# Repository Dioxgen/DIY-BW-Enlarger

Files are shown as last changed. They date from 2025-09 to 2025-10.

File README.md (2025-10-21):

# 基于 RGB 光源的黑白放大机设计笔记

###### 【Designed By Dioxgen】  

## 概述：

如题，这是一篇关于 DIY 黑白放大机的笔记。该放大机的核心材料为**黑胡桃木 + 金属**，DIY 特点在于通过 RGB 光源替代传统的方案、引入精准对焦系统、设计兼容多画幅底片磁吸片夹等，实现低成本、高自由度的黑白暗房创作。

本项目尽量兼顾**功能与成本**的平衡，确保可行性以便于复刻。按照惯例，全部资料开源处理。

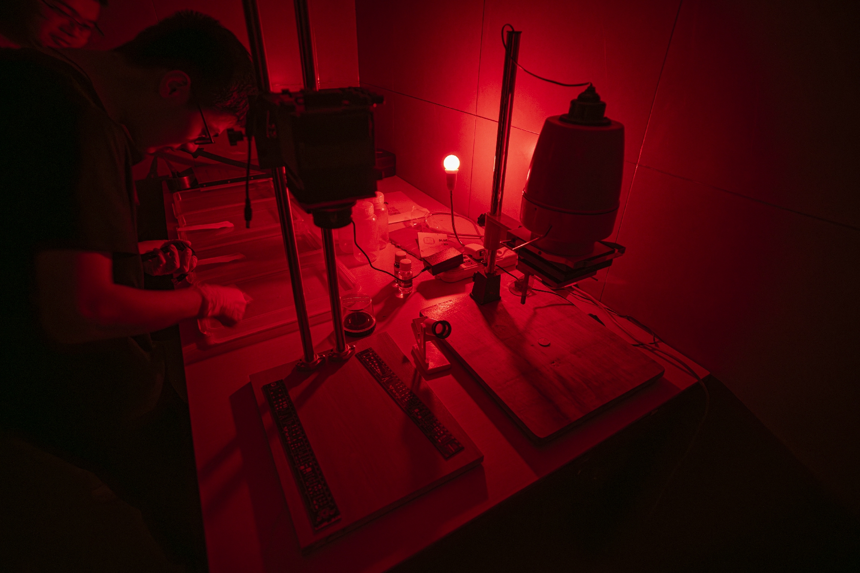
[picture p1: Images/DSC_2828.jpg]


### FAQ：

成本如何？

> < 400￥

耗时？

> 3 天收集材料，3 天组装，一周可完成。

支持的底片？

> 135 底片与 66 画幅底片。为黑白负片设计，彩色负片**可能**不适用。

放大倍率？

> 可以自由组合底板大小与主杆的高度，设计为至少放大 8 倍。（最大倍率也取决于放大镜头）

操控方面？

> 滑块移动主体，滑台移动对焦组，整机精度可用。

如何复刻？

> 接着看下去。

### 版本组合：

| 总版本 | 片夹 | PCB  |
| --- | ---- | ---- |
| 1.0 | 1.0  | 1.0  |
| 2.0 | 2.0  | 2.0  |

| 具体项目 | 版本 | 说明 |
| --- | --- | --- |
| 片夹 | 1.0 | 多玻璃易产生牛顿环 |
| | 2.0（待完成） | 单玻璃 |
| PCB | 1.0 | 电位器正负极混乱，单联电位器不稳定 |
| | 2.0 | 解决V1.0问题，优化布局 |

> *（截至 2025.08）*

## 结构设计：

该放大机的基本结构由我参考了杜斯特（Durst）的各类放大机的共性设计，并结合本人 DIY 与嵌入式开发经验做出改动迭代得到。

主材料选择了胡桃木，其油分不足，需要做木蜡保护。

### 主杆：

主杆由两长度 **1m**，**Φ=20mm** 的钢轴，搭配 **SCS20UU** 带锁紧的滑块制成。将轴切割后插入底座打好的孔洞中，再用法兰座进一步固定即可。

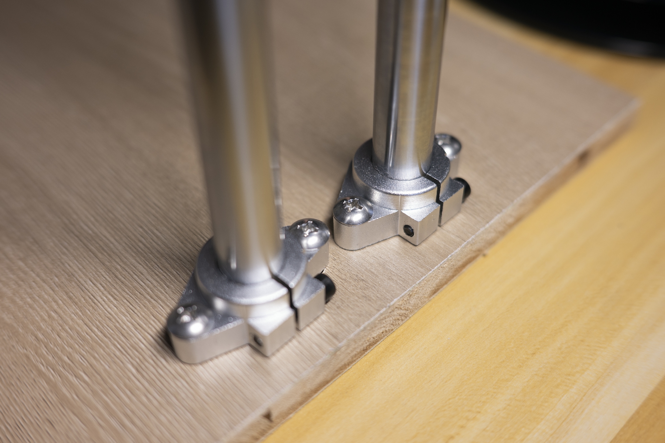
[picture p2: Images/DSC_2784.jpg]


这两根钢轴若是实心的，则奇重无比。取碳钢密度为 *7850kg/m³*，则总质量（2x1m）约为 *4.9kg*，实际镀铬硬轴会更重。若选用外径 *20mm*，内径 *15mm* 钢管，这一数值可缩减至 *2.15kg*。但注意钢管的**公差**会大很多，可能导致连法兰座都无法安装，且**直线度**远低于镀铬硬轴，另外异味较重。

将滑块插入钢轴，随后，使用木板连接两滑块，放大机主体可与其通过角码进一步连接。

------

### 底座：

从强度、形变、成本等方面综合考虑，我最终选择了一整块 30×37.5×2cm 的**胶合木板**作为底板，预留两处孔洞装配主杆，底部装配四处防滑垫。

> 详细的论述可以参考`\Datasheet\其他\底板推导.md`

------

### 光源：

光源的选择与所要处理的感光材料息息相关。本项目制作的是黑白放大机，选择的光源优先适配**黑白相纸**。

从材质上看，黑白相纸分为 FB 纸基相纸（Fiber-based）和 RC 涂塑相纸。涂塑相纸表面涂布 PE（Polyethylene，聚乙烯）。

可变反差黑白相纸的乳剂可以理解为由两层构成：

> 1. 高反差层：感蓝光。
> 2. 低反差层：感绿光。
>

相纸最终反差取决于两层乳剂的**曝光比例**，而可变反差滤镜（Variable Contrast Filters，即 VC 滤镜）作为黑白暗房放大中的关键工具，其核心原理就是通过**色光选择性调控**，利用黑白相纸乳剂对不同色光的敏感性差异，通过控制蓝光与绿光的入射强度比例实现调节相纸反差的效果。

> 操作举例：使用 Y（黄色）滤镜过滤蓝光实现低反差； M（品红）滤镜过滤绿光实现高反差。

我最终选择了**凯瑞的可变反差黑白涂塑相纸（KENTMERE VC SELECT RC）**，~~因为便宜~~，那么基于其特性进一步考虑光源的选择：

#### 1）卤素灯：

传统的放大机光源大多为**卤素灯**，光谱连续且覆盖完整（显色指数 CRI > 95），能充分激发相纸乳剂。然而灯泡寿命较短（约 50 小时）且功耗较大，长时间曝光还易引发烤片等问题。

#### 2）普通白光 LED：

普通 LED 红外辐射少、能耗低、寿命极长。然而观察光谱可知蓝光峰突出且 480nm 附近波段严重不足，CRI 通常 ≤ 80，缺乏连续光谱，不适合相纸曝光。

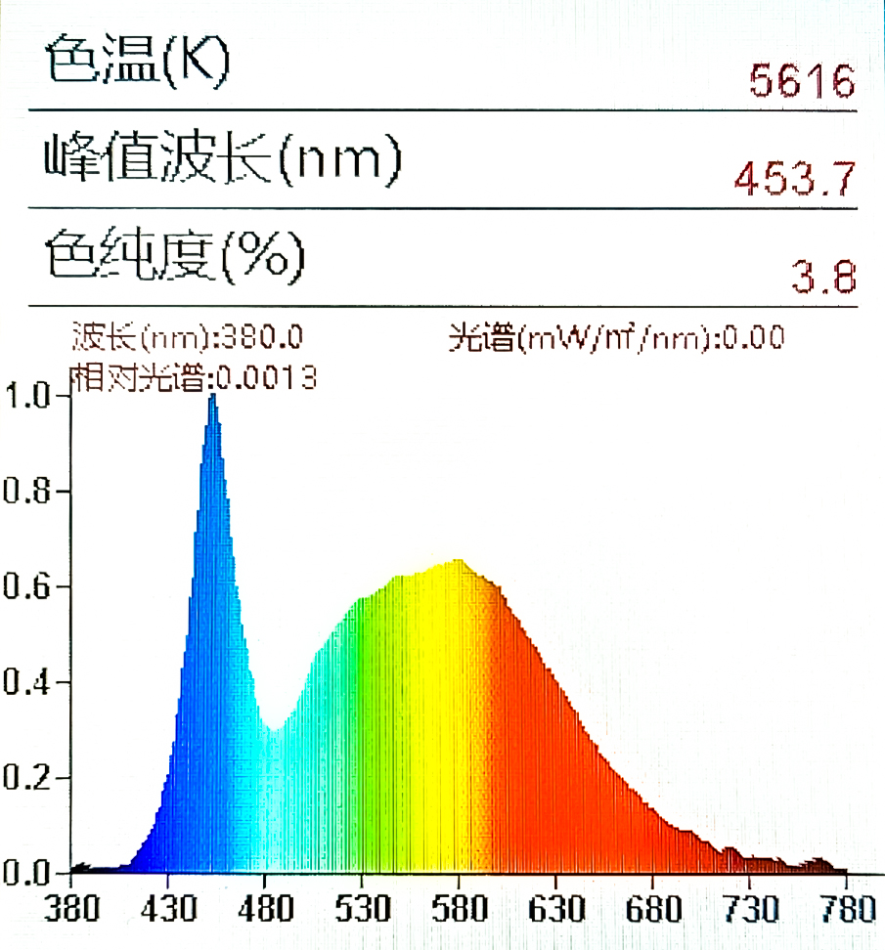
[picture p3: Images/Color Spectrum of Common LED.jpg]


<center>普通 LED 实测光谱拍屏</center>

##### # 特殊的高 CRI LED：

可以使用单个 **COB 光源**，通过菲涅尔透镜获得平行光，也是一种适宜的解决方案。

#### 3）RGB 灯珠：

通过独立控制红（R）、绿（G）、蓝（B）三通道亮度，直接调控相纸双层乳剂的激活比例，无需物理滤镜。

##### # 核心原理：

- 绿光（G） → 激活低反差层 → 降低反差
- 蓝光（B） → 激活高反差层 → 提高反差
- 红光（R） → 黑白相纸几乎不感光，可用于安全灯模式。

| RGB灯珠 | 每通道独立控制输出 |
| :---: | :---: |
| **混光系统** | **扩散板确保光场均匀** |
| **驱动电路** | **PWM 控制色光比例** |
| **控制界面** | **实体按键与旋钮（详见“电控系统”）** |

最常见的 RGB 灯珠莫过于 **5050RGB** 灯珠，该灯珠的数据手册我已归档于 “Datasheet” 文件夹中。其中最重要的参数是光谱：

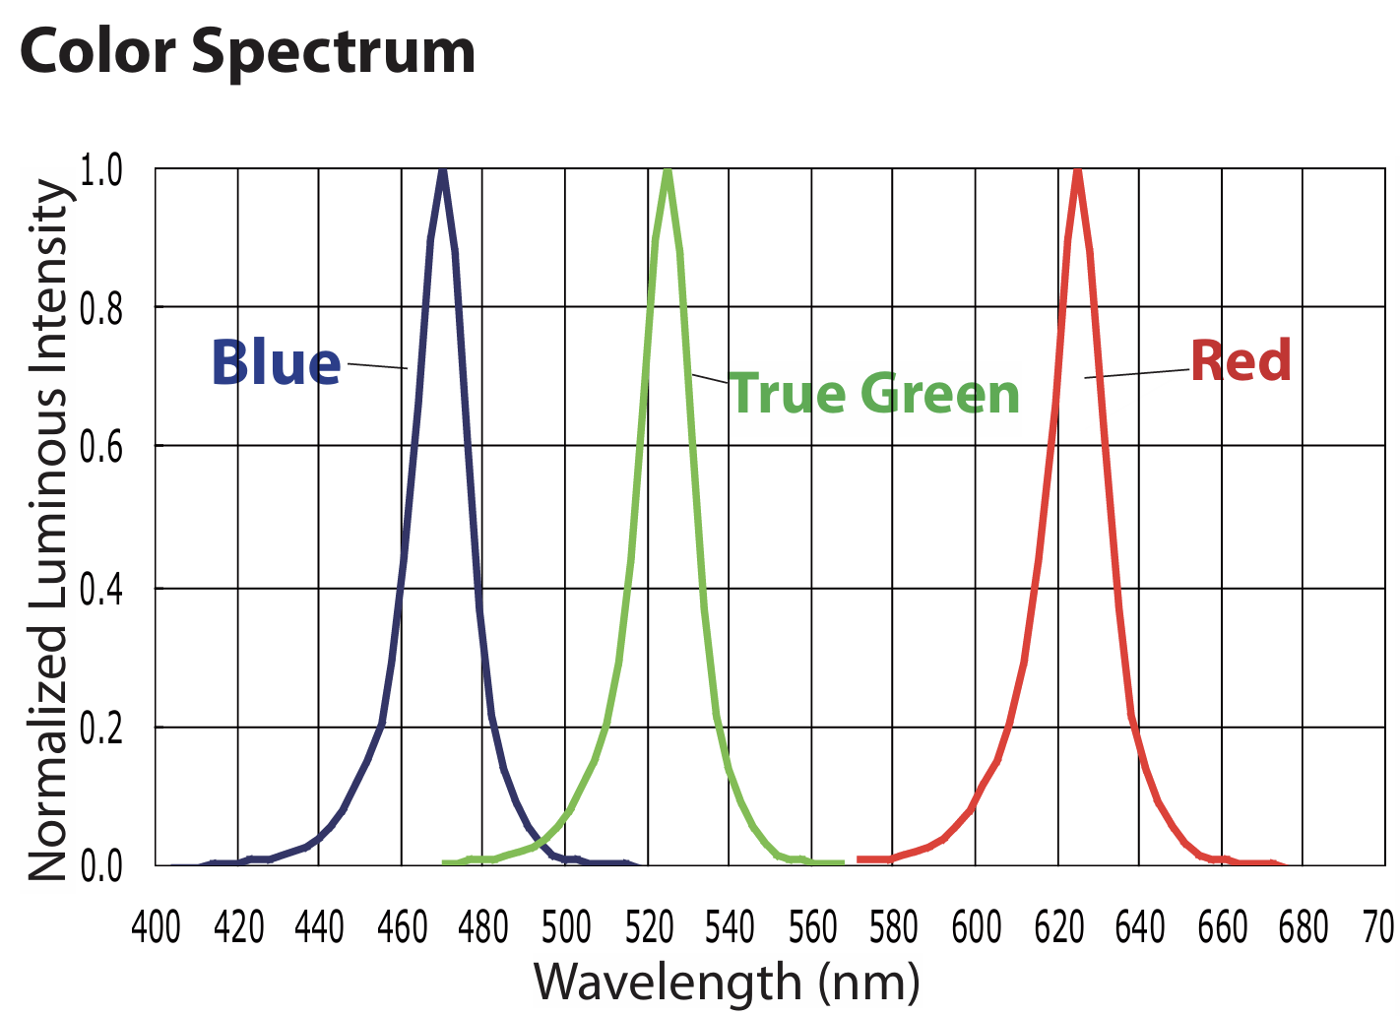
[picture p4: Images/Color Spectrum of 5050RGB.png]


| 颜色 | 最小值（nm） | 典型值（nm） | 最大值（nm） |
| ---- | --- | --- | --- |
| R | 620 | 625 | 630 |
| G | 520 | 525 | 530 |
| B | 460 | 465 | 470 |

单个灯珠最大功耗约 0.3W，使用 8×8 灯板则总功率在 **19W** 左右，比较合适。既然使用灯板，那么通过均光板混光即可。

#### 相纸：

关于 **KENTMERE VC SELECT RC** 的手册中未提及有关波长响应曲线的资料，只在 “Exposure” 中提到：

> VC SELECT is designed for use with **tungsten or tungsten halogen light sources**.
>
> Cold light source enlargers can be used, but they may **limit the contrast range achievable**. 

大意是该相纸被设计用于**钨丝灯或卤素灯光源**，使用冷光源可能导致**低反差**。

但是，我在[KENTMERE PHOTOGRAPHIC : VC SELECT TECHNICAL DATA](https://www.digitaltruth.com/products/kentmere_tech/Kentmere_VC_Select.pdf)中发现了该资料：

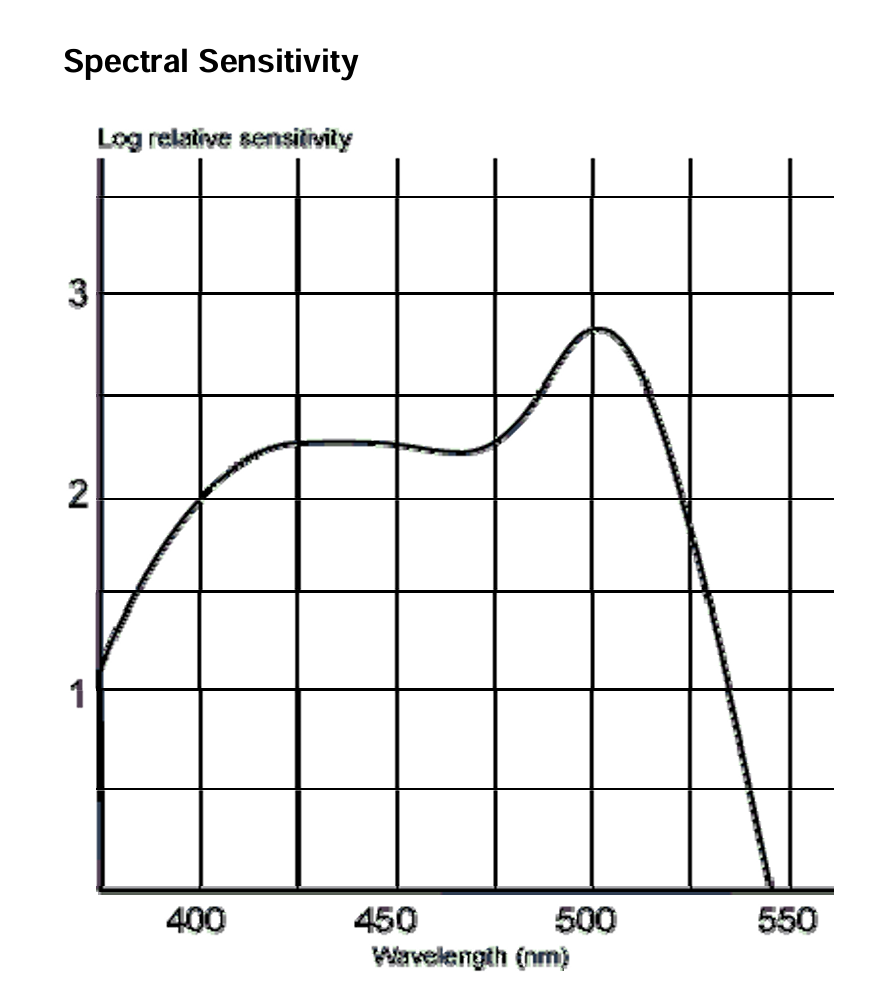
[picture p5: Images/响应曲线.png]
响应曲线


由此可见，比对刚才 RGB 光源的光谱，可以发现相纸对 RGB 的**绿光少敏感**，蓝光完全**在响应范围**内。光源的 G 通道是 520-530nm，B 通道是 460-470nm。由于相纸的响应范围到 525nm，而 G 光源的典型值是 525nm，刚好在边缘，所以 G 光源应该能激活相纸的低反差层。B 光源的 460~470nm 在相纸的响应范围内，应该能激活高反差层。

在标准 VC 相纸中，蓝光用于高反差，绿光用于低反差。但这里相纸的响应范围只到 525nm，且尖峰在 500nm，所以对于 G 光源的 525nm，响应可能稍弱。

基于光谱响应，我们可以估计 G 和 B 通道的曝光时间比例与反差号数的关系。但需要注意的是，由于相纸灵敏度和光源光强可能存在差异，以下估计为**理论值**：

| 反差号数 | B/G 比例范围 | 典型 G-B 组合 | 组合说明 |
| :--- | :--- | :--- | :--- |
| 0 | 0 | (9,0) | 只有绿光，激活低反差层，反差最低 |
| 1 | 0.2 ~ 0.3 | (4,1) | 绿光主导，蓝光微弱，反差略高 |
| 2 | 0.5 ~ 1.0 | (3,2) | 绿光与蓝光平衡偏绿，反差中等 |
| 3 | 1.5 ~ 2.2 | (2,3) | 蓝光与绿光平衡偏蓝，反差中高 |
| 4 | 4.0 ~ 7.0 | (1,4) | 蓝光主导，绿光微弱，反差很高 |
| 5 | ∞ | (0,9) | 只有蓝光，激活高反差层，反差最高 |

后来实际测试，发现 B 通道在 3~6 处相纸反差变化巨大，G 通道总设置为 9 为宜，该现象与上文预测基本吻合。

如果你认为效果欠佳，则再改装为高 CRI 的 COB 光源为宜。

------

### 对焦组：

设计对焦组时需明确对焦行程，该数据可由暗房放大的需求来计算得到。

例1. 假设使用焦段为 **50mm** 的放大镜头将标准的**全画幅**底片放大 **4~8** 倍（对应大约 4x5 至 8x10），则：

1）放大倍率（m）为：
$$
m=\frac{v}{u}
$$
2）透镜公式：
$$
\frac{1}{f}=\frac{1}{u}+\frac{1}{v}
$$
3）结合两公式，可推导出：

1. 物距（1式）：

$$
u=f\cdot\frac{m+1}{m}
$$

2. 像距：

$$
v=f\cdot(m+1)
$$

> 其中：
>
> - f 为镜头焦距（mm）
> - m 为放大倍率
> - u 和 v 的单位为毫米（mm）

4）代入 f 与 m ，得：
$$
m=4时，u=62.5mm，v=250mm
$$

$$
m=8时，u=56.25mm，v=450mm
$$

例2. 假设使用焦段为 **75mm** 的放大镜头将 **66 画幅**中画幅底片放大 **2~4** 倍，同理可得：
$$
m=2时，u=112.5mm，v=225mm
$$

$$
m=4时，u=93.75mm，v=375mm
$$

根据以上数据以及他人反映，应加入冗余设计，考虑到钢轴可能难以加工，则直接使用 **1m** 的即可。对焦组使用行程在 **60~70mm** 的滑台为宜。

##### # 注意：

> 在以上推导中，物距 u 是物体（底片）到镜头的距离；像距 v 是镜头到像（相纸）的距离，不要弄反。
>
> 放大镜头的法兰距（FFD）在此处一般不会对机械设计造成影响。但在某些极端情况下，当期望实现高放大倍率所需的 u 小于 FFD 时，因为对焦操作成像后实际能达到的最小 u 总是 ≥ FFD，所以此时实际的 u ≥ 期望的 u。而根据（1式），在 f 不变的前提下，实际放大倍率 m 将会减小。即镜头无法被调整到足够靠近底片的位置，从而无法达到所需的较高放大倍率，且机械结构可能已达到其调节极限。
>
> 本项目基础卡口为 EF 卡口（FFD ≈ 44mm），可转接放大镜头中更常规的 M39 卡口（FFD = 45.3mm，螺距 1/26 英寸，约 0.977mm）使用。

#### 主要部件：

##### 滑台：

我选择了 **LWZ40-90L** 燕尾槽滑台作为对焦组的核心部件，该组件行程约 70mm，带锁紧，其精密度满足对焦需要。

> 注意是 Z 轴滑台而非 X 轴滑台，Z 轴滑台特有的部件方便了机械设计。

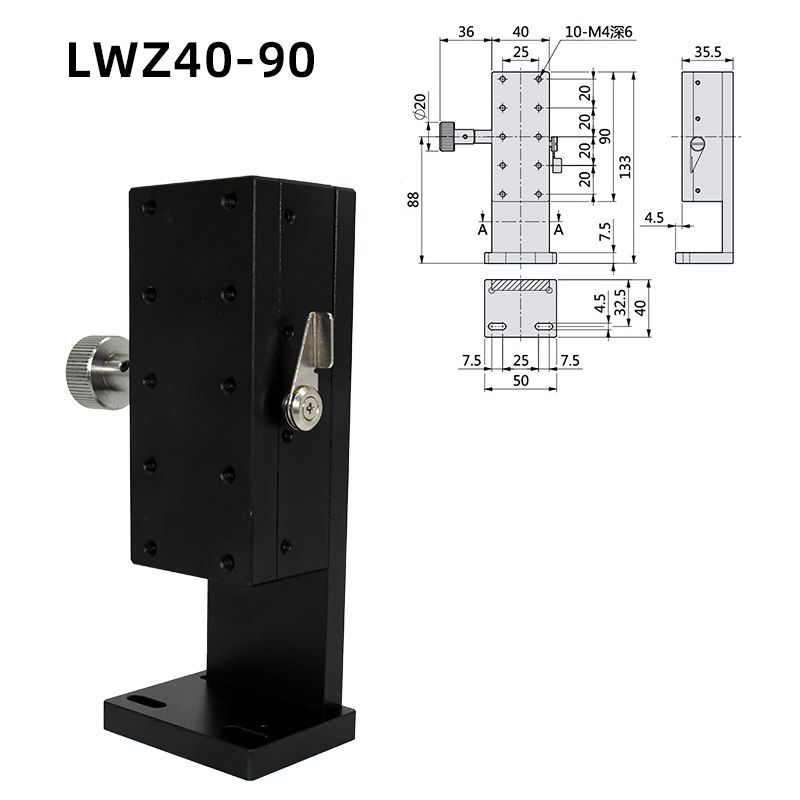
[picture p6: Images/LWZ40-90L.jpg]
LWZ40-90L


<center>示意图</center>

##### 皮腔：

皮腔由**两层春亚纺**配合激光切割纸质衬条制作，详情可见我的上一篇自制 5×7 大画幅文档。

> 参数：
>
> A = 8mm
>
> B = 80mm
>
> C = 120mm
>
> D = 80mm

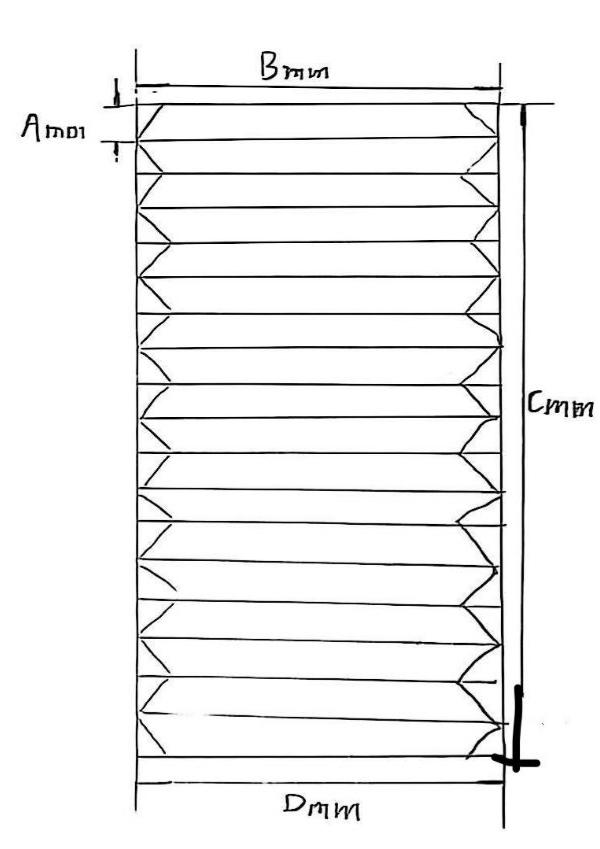
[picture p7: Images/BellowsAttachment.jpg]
BellowsAttachment


<center>示意图</center>

##### 卡口：

上文提到我使用了 **EF 卡口**作为放大机卡口，原因主要有以下几点：

> 1. EF 卡口存在现成配件方便设计结构。
> 2. EF 卡口转接性能优异，常规 M39 等放大镜头此处可完美适配。还可尝试非常规镜头的放大效果。
> 3. 可以盘活我闲置的 EF 镜头。

你也可以**直接**将 M39 转 XXX 环粘连到镜头板上以免去 EF 卡口部件，但保留该部件可以方便日后使用不同卡口镜头。这也是本项目使用 EF 卡口的初衷。

###### # 注意：

> 摄影镜头可临时替代放大机镜头，但存在光学性能、操作兼容性等方面的限制。如像场平坦度控制、边缘画质、色差、通光均一性等。
>
> 以下是关于放大镜头经典结构的一般归纳：
>
> | 结构类型         | 镜片组构成 | 最大光圈范围 | 描述       |
> | :--------------- | :--------- | :----------- | :--------- |
> | 三片式（柯克型） | 3 片 3 组  | 通常较小     | 性能一般   |
> | 四片式（天塞型） | 4 片 3 组  | f/4 左右     | 性价比之选 |
> | 六片式（高斯型） | 6 片 4 组  | f/2.8~f/5.6  | 像质较佳   |
> | APO 复消色差     | 通常 > 6片 | 同六片式     | 专业放大   |

------

### 片夹：

该放大机应当能支持 135 底片与 66 画幅底片的放大。我准备使用**磁吸**片夹将底片夹于两片玻璃之间（V1.0），设计 66 画幅与 135 两种格式。即该片夹为**两层式**设计，一层复用，另一层分 135 与 66 两种。为方便操作，还设计了适配胶片宽度的斜面，可用于胶片快速复位。

普通玻璃易出现**牛顿环**影响成像效果，可以使用细磨砂玻璃、抗牛顿环玻璃（本质也是磨砂）、磨砂贴膜的白玻璃等解决，即避免胶片光面和玻璃光面接触。

后来重新设计片夹（V2.0），只在上层设置玻璃。不仅可以节约成本，还能避免牛顿环问题。此处胶片的平整度问题不必过于担心。

------

### 电控系统：

#### 使用方法：

1. 启动系统后默认进入调光模式
2. 旋转电位器调整光源颜色和亮度
3. 按下模式选择按钮切换到曝光模式
4. 短按开始按钮选择曝光时间
5. 长按开始按钮进入等待曝光状态
6. 再次按下开始按钮开始曝光
7. 曝光完成后自动返回曝光模式

#### 主要硬件：

##### 1）电源：

> RGB 灯板总功率约 19W，我选择了 5V 5A 电源适配器供电，使用 DC 5.5×2.5mm 通用接口。
>
> 建议选择较长的电源线。

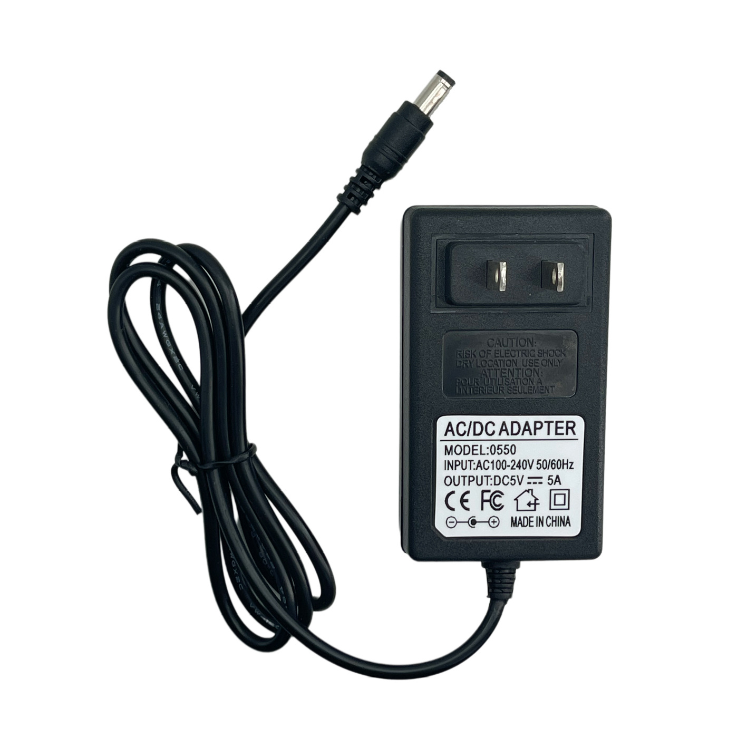
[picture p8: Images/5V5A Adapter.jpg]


##### 2）控制器：

> RGB 灯板的工作电压为 DC 5V，使用 **Arduino** 可兼顾成本与开发难度。本项目没有小体积要求，直接使用现成的 **Arduino Nano** 开发板通过排母连接主板即可。
>
> 理论上通过单片机编程，可以实现超精确曝光调整、256 级，16777216 种色光调控以及其他个性化需求。实际在调光中选择了每通道（包括总亮度） 0~9 共 10 个等级，1000 （1w）种组合。

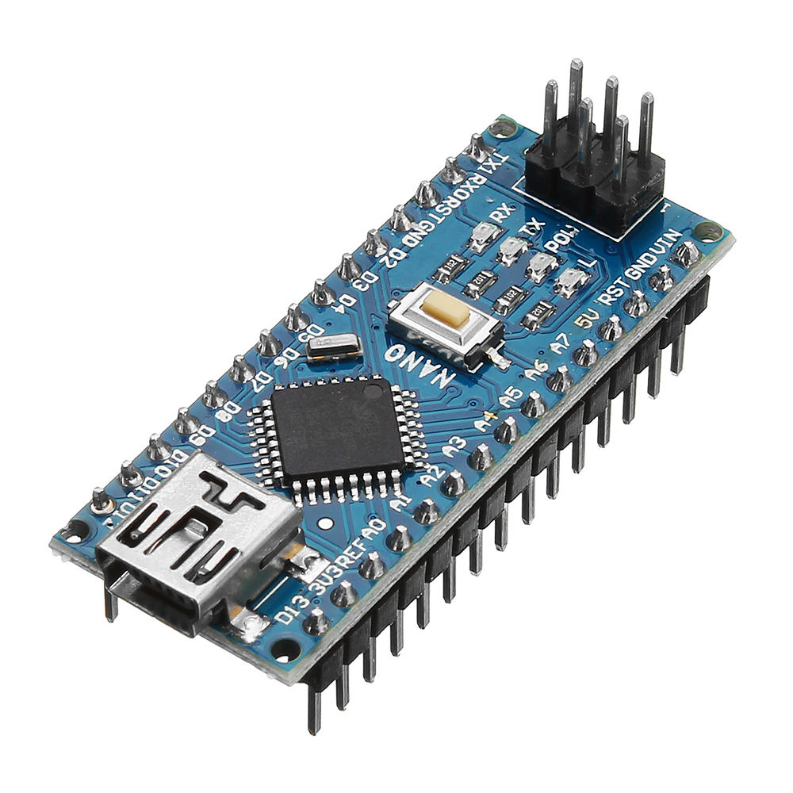
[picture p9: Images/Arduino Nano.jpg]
Arduino Nano


##### 3）LCD1602A

> 已在程序中启用屏幕背光自动关闭以防止杂光。应当选择黑底红字的屏幕，进一步防止杂光。

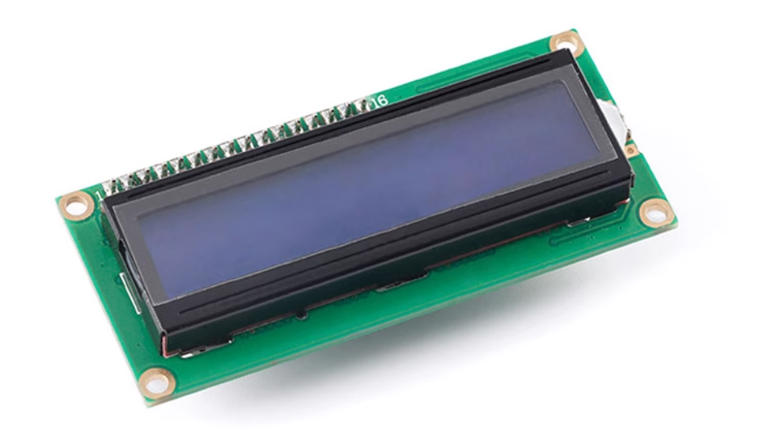
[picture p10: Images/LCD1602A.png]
LCD1602A


##### 4）WS2812 64 位灯板

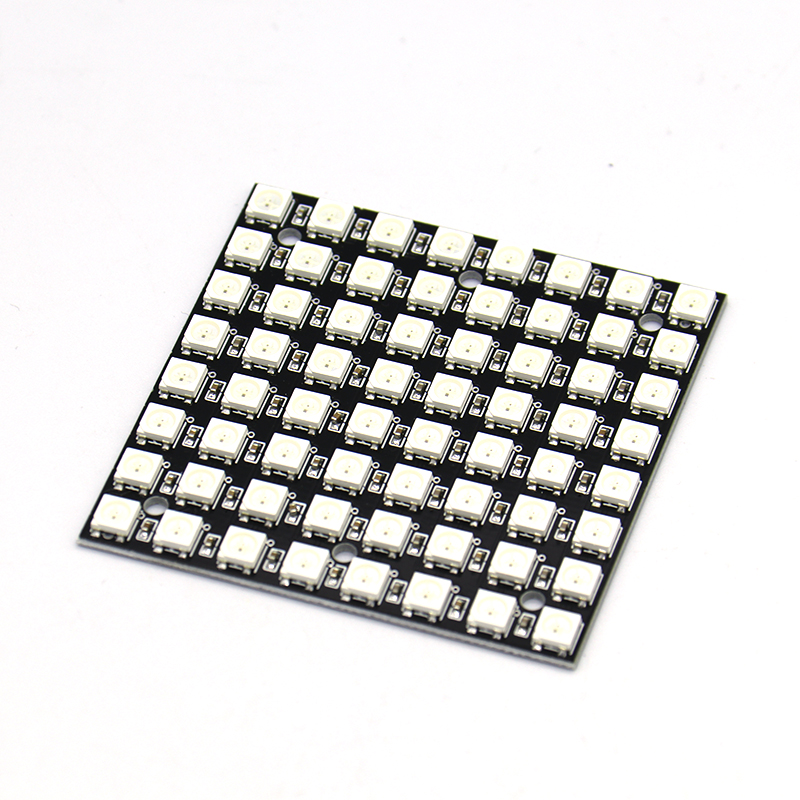
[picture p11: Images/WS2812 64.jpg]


##### 5）其他元件（V2.0 为双联电位器）

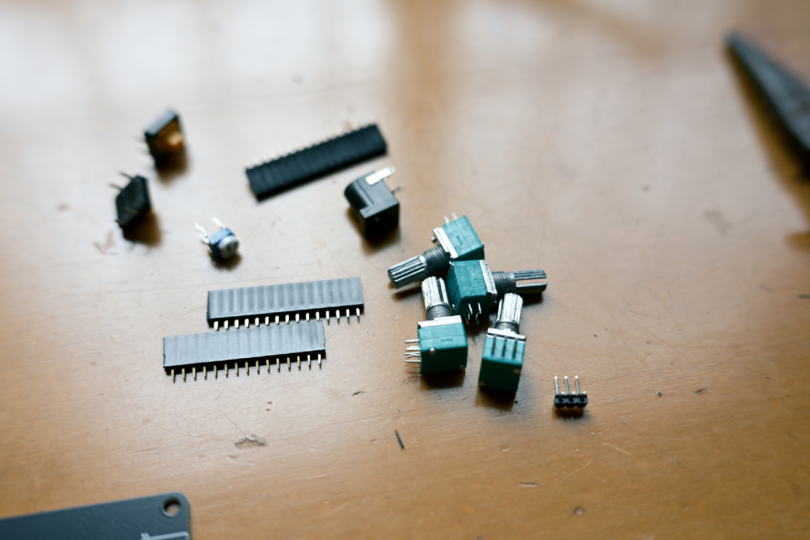
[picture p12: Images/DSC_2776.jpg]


#### 交互：

用户可通过**微动开关**设置模式和参数等，三个**电位器**设置 RGB 通道，一个电位器设置亮度。我使用了 **LCD1602A** 屏幕以提供操作反馈。

#### PCB：

##### V1.0：

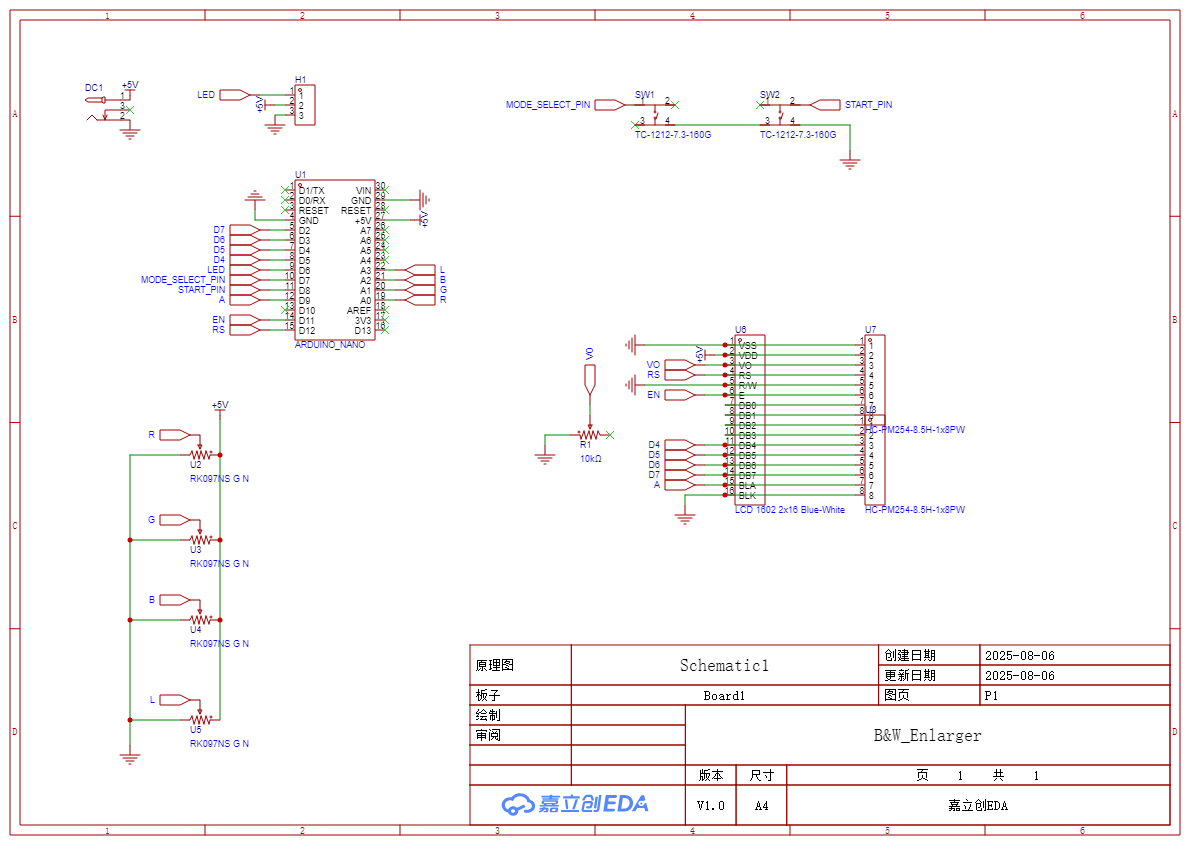
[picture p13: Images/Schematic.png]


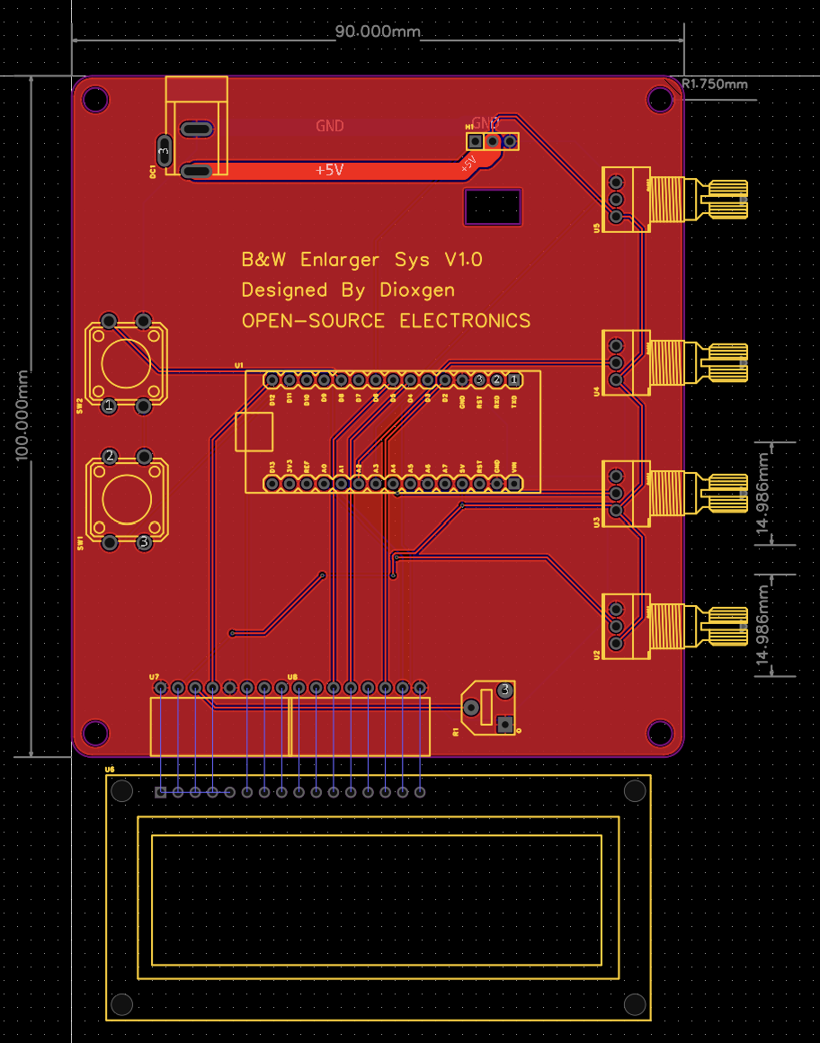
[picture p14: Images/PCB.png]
PCB


> 注：V1.0 PCB 存在电位器正负极反向的问题，可在代码中选择注释相应部分适配。核心为替换`map()`中`DEADZONE_LOW`以及`DEADZONE_HIGH`的位置。

##### V2.0：

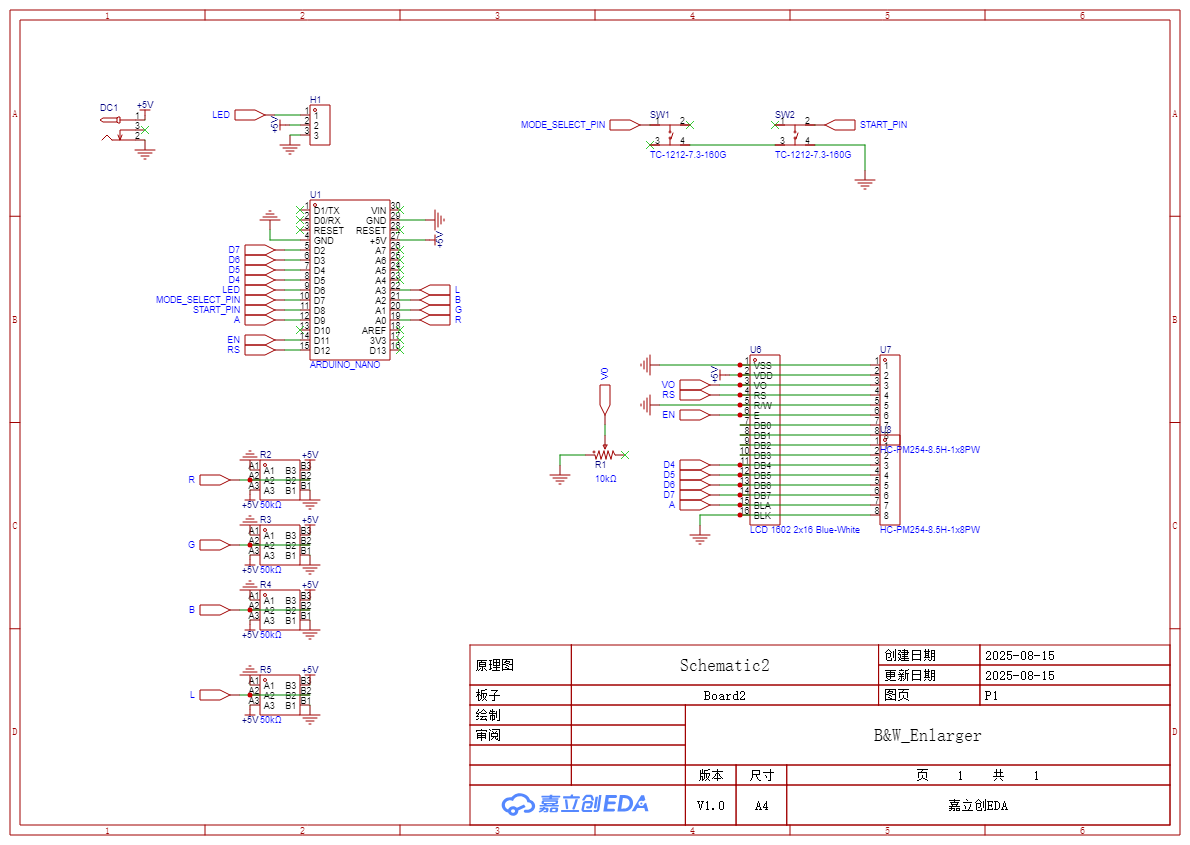
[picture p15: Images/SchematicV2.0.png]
SchematicV2.0


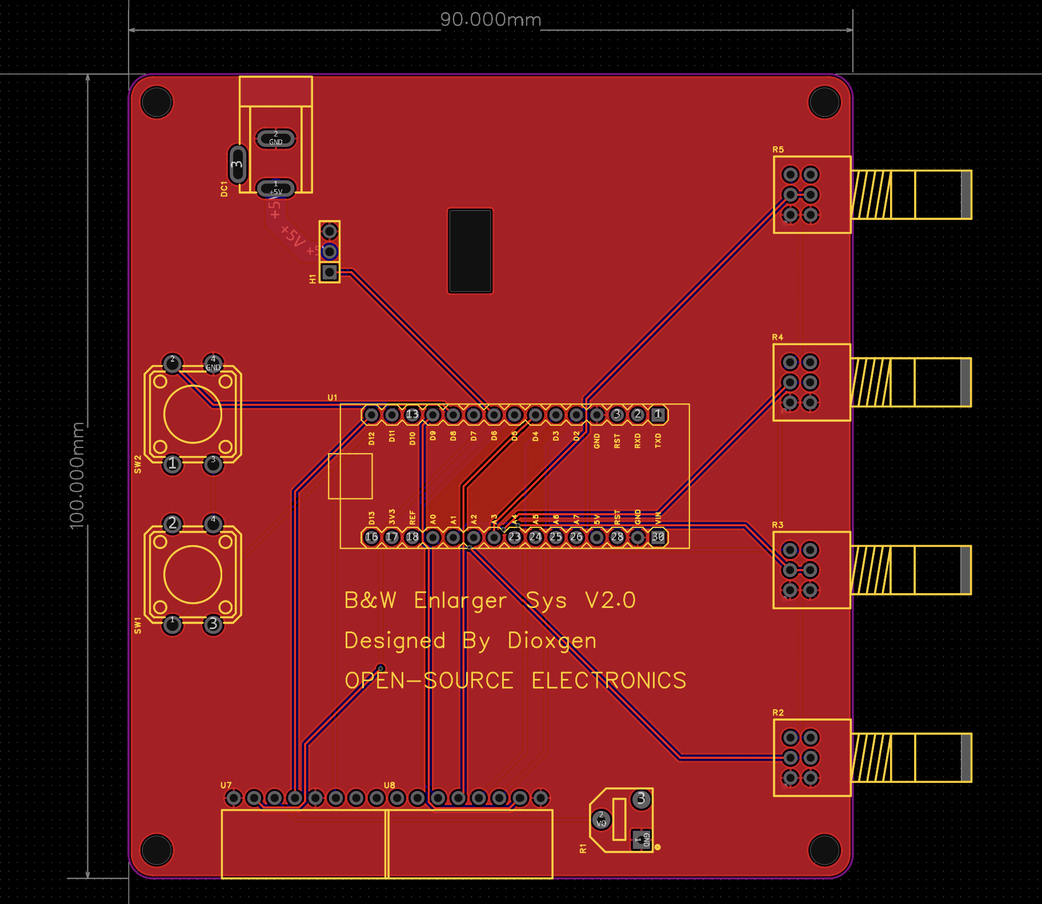
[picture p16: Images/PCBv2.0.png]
PCBv2.0


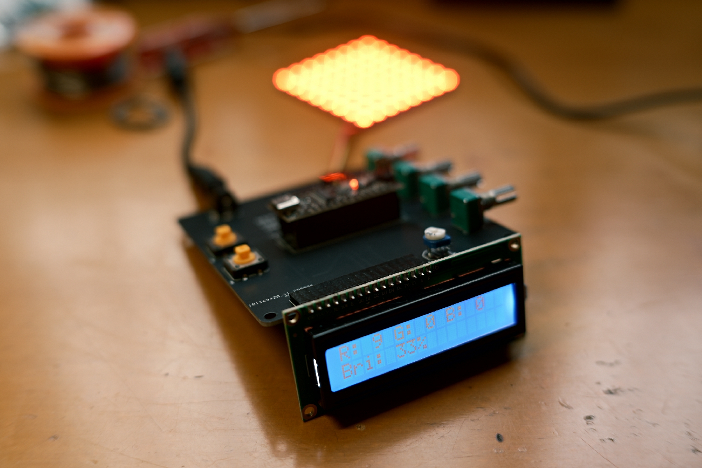
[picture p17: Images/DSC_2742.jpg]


<center>实物图是 V1.0 PCB</center>

#### 程序：

程序的核心在于**调光**和**曝光**两大功能的实现，我使用了 **Arduino IDE 2.3.6** 进行编写。

程序提供两种工作模式：调光模式和曝光模式。

关于引脚定义的部分已在源代码中明确。

> 使用到的库：
>
> Adafruit NeoPixel 1.15.1
>
> LiquidCrystal 1.0.7

##### 主要函数：

- `setup()`：初始化硬件
- `loop()`：根据当前模式调用调光或曝光功能
- `Dimming()`：处理调光模式的逻辑
- `Exposure()`：处理曝光模式的逻辑
- `calibratedRead()`：带死区处理的电位器读取
- `updateLCD()`：更新调光模式显示
- `updateExposureLCD()`：更新曝光时间显示
- `START_ENLARGE()`：执行曝光过程

##### 1）调光：

关于调光，我使用了代表 R、G、B 的三个 10K 电位器，将 Arduino 的 ADC 从中读取到的值从 0-1023 映射至 0-9。同时为避免在某些情况下（可能是电源不稳）电位器在极限位置时无法达到理想的 0 或 1023 值，导致颜色不纯的问题，我放弃滤波算法，通过**校准和死区处理**确保了纯净颜色。旋转电位器可以实时看见色光的变化，当且仅当**只启用 R 通道**时，屏幕背光将自动关闭，即为安全灯模式，其他情况下背光将开启。

基本流程：读取 DAC （`Raw` 值），若 < 30，则返回 0；大于 1000，则返回 1023，否则映射至 0-1023。再映射（`map()`）至 0-9 获得等级数（`level` 值），随后据此查表（`colorLevels[LEVELS]`）获取对应 RGB 值（`val` 值），最后推送给 WS2812（`pixels.setPixelColor(i, pixels.Color(R_val, G_val, B_val))`）。

###### 校准系统：

> - 使用`calibratedRead()`函数处理电位器极限值。
> - 设置死区范围：`DEADZONE_LOW = 30`，`DEADZONE_HIGH = 1000`

###### 纯净颜色：

```c
// 死区处理 - 确保极限位置返回0或1023
if (raw < DEADZONE_LOW) return 0;
if (raw > DEADZONE_HIGH) return 1023;
```

> - 当电位器低于 30 时，强制返回 0。
> - 当电位器高于 1000 时，强制返回 1023。
> - 中间值线性映射到 0~1023 范围。

###### 10 级映射：

> - 定义了 10 个等级常量：`const int LEVELS = 10;`
> - 创建颜色查找表：`colorLevels[10] = {0, 28, 56, 85, 113, 141, 170, 198, 226, 255}`
> - 映射到 0~9 等级：`map(rRaw, 0, 1023, 0, LEVELS-1)`

##### 2）曝光：

该模式有两个状态：**调整曝光时间**状态（`EXPOSURE_ADJUST`）和**等待开始曝光**状态（`EXPOSURE_WAITING`）。通过分析“开始”按键为短按还是长按，分别进行调整`ExpTime_level`以通过`ExpTimeLevels[ExpTime_level]`获取曝光时长（ms）和进入等待曝光界面的操作。**在等待曝光界面，将会启用安全灯，并关闭背光**。再次按下“开始”按键 5s 后即通过`START_ENLARGE(int EXPOSURE_TIME, int R, int G, int B, int L)`开始曝光。

###### 基本逻辑：

> - 短按选择按钮切换曝光时间
> - 长按选择按钮进入等待曝光状态
> - 再次按下按钮开始曝光
> - LCD 背光在曝光前关闭防止漏光
> - 曝光完成后显示完成信息

###### 短长按辨别：

> - 等到检测到按键持续按下时间超过`LONG_PRESS_THRESHOLD`判断为长按。

------

### 2.0 清单：

#### 五金类：

| 项目 | 数量 | 备注 |
| --- | ---- | --- |
| EF 反接卡口保护环  | 1 | 卡口组件 |
| LWZ40-90L | 1 | Z轴燕尾槽 对焦组件 |
| 不锈钢角码90度 | 2 | |
| 不锈钢角码12*15 | 2 | 连接滑台与镜头板 |
| 均光板 | 1 | 70 * 80 * 3mm |
| 玻璃 | 2 | 60 * 60 * 2mm |
| 卧式SHF20 | 2 | 光轴支撑座 |
| 外径20（内径15）1m | 2 | 主杆 |
| SCS20UU | 2 | 滑块带锁紧 |
| 10 * 5 * 2mm | 12 | 方形钕磁铁 |
| M2*8 | 4 | 自攻螺丝（PCB固定） |
| M6 * 20 * 12 | 4 | 黑色扁头螺丝（固定滑块） |
| M4*14 | 2 | 黑色自攻螺丝（固定滑台） |
| M6*20 | 4 | 自攻螺丝（固定法兰座） |
| M4*6 | 10 | 大扁头自攻螺丝（2个连接小角码） |
| M4*8 | 2 | 圆头螺丝（连接小角码） |

#### 电气类：

| 项目 | 数量 | 备注 |
| --- | ---- | --- |
| 5V5A适配器 | 1 | 尽量 ≥ 4A |
| WS2812 64 位灯板 | 1 | |
| LCD1602A | 1 | 5V 版本，黑底红字 |
| Arduino Nano | 1 | Atmega328p 主控 |
| DC 5.5×2.5mm 接口 | 1 | |
| RK097G-B10K | 4 | 10K双联六脚电位器 |
| RM065 10K | 1 | LCD对比度调节电阻 |
| WH148 AG2 | 4 | 红、绿、蓝、白旋钮帽 |
| TC-1212-7.3 | 2 | 方形微动开关 |
| HC-PM254-8.5H-1x16PW | 1 | 单弯母16P（连接LCD） |
| HDR-PM254-1x3P | 1 | 弯排针（连接LED） |

#### 木板：

| 序号 | 尺寸（mm） | 数量 | 备注 |
| ---- | --- | ---- | --- |
| 1 | 100 * 120 * 10 | 1 | ① |
| 2 | 175 * 90 * 10  | 1 | ② |
| 3 | 45 * 80 * 5 | 1 | ③ |
| 4 | 80 * 50 * 5 | 2 | ⑥/⑥* |
| 5 | 80 * 60 * 5 | 1 | ⑤ |
| 6 | 80 * 90 * 5 | 1 | ⑤*（加工） |
| 7 | 90 * 85 * 5 | 1 | 镜头板 |
| 8 | 300 * 375 * 20 | 1 | 胶合板底板 |

> 注：木板位置可**参考**图纸上的标记；1~7 为黑胡桃木。期间经历多次改版，图纸可能**不完全正确**，具体可看下文图示。
>
> 纠错：④、⑦与⑦*、片夹123实际均不存在；⑤、三处M4螺丝、大角码尺寸错误；RGB应紧贴②；均光板距RGB应为20mm。LWZ40-90与镜头板靠小角码连接。

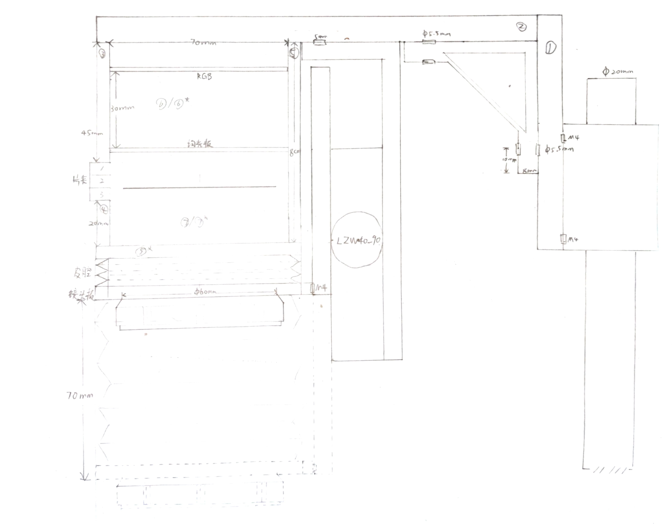
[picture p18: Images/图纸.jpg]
图纸


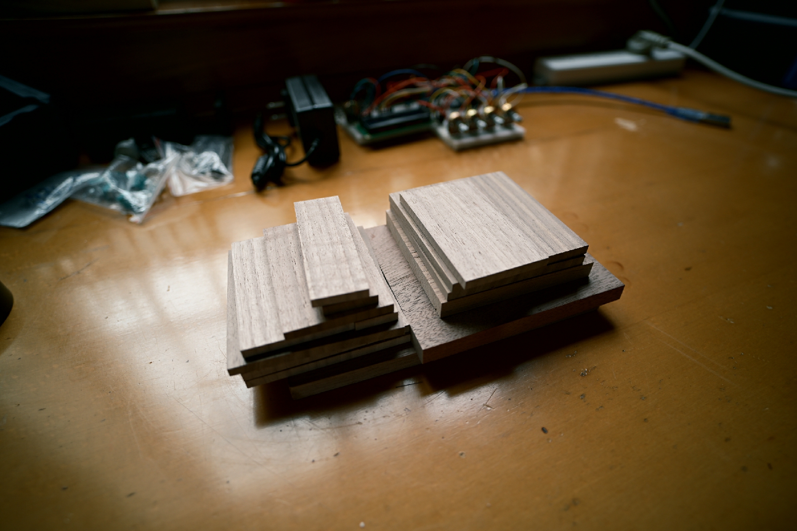
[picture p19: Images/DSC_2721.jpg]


#### 片夹：

片夹结构特殊需 3D 打印。`Mechanical`文件夹中给出了 3 种片夹的 stl 文件。每种一份，建议选择黑色 PETG + 15% 填充打印。

## 组装：

找木材店铺按照上文给出尺寸定制木板，然后以下零件需再次加工：

> ⑤
>
> 镜头板
>
> 底板

请按照`Mechanical`文件夹中给出的图纸切割对应木板。或者，可以在前期定制中一起解决。

准备 4、7mm 钻头，可用于螺丝定位以及非自攻螺丝的开孔。

请按照图纸粘连木板，胶水我使用了**泰特邦木工胶**，木工夹固定，成型后用砂纸打磨，最后上**三青固体木蜡油**。

按图所示位置放置角码等五金部件。

#### 使用`PCB`文件夹中的 Gerber 文件嘉立创打样，焊接，上传代码至单片机：

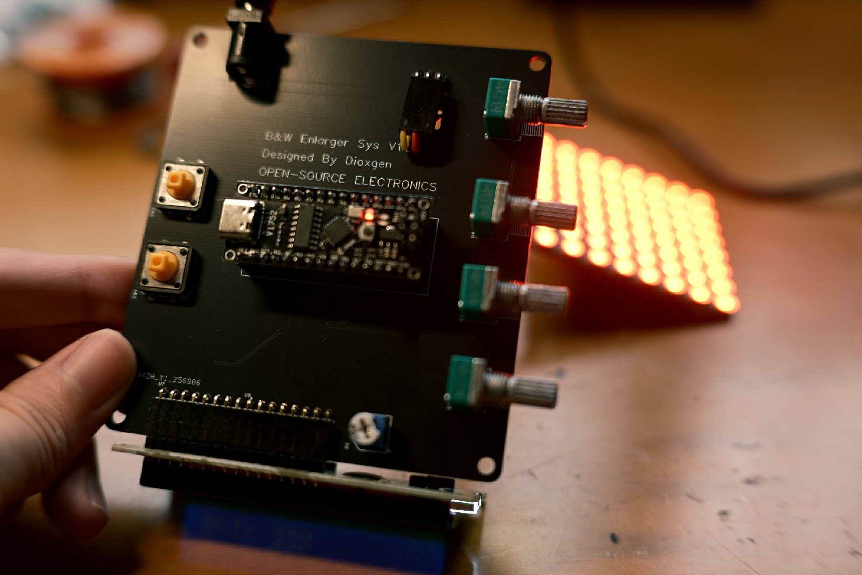
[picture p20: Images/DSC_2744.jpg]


#### 序号 1~5、 RGB 灯板、均光板的粘接：

> 可以在⑥板边缘或者②板上开小孔引出灯板的三根线束（推荐前者）。

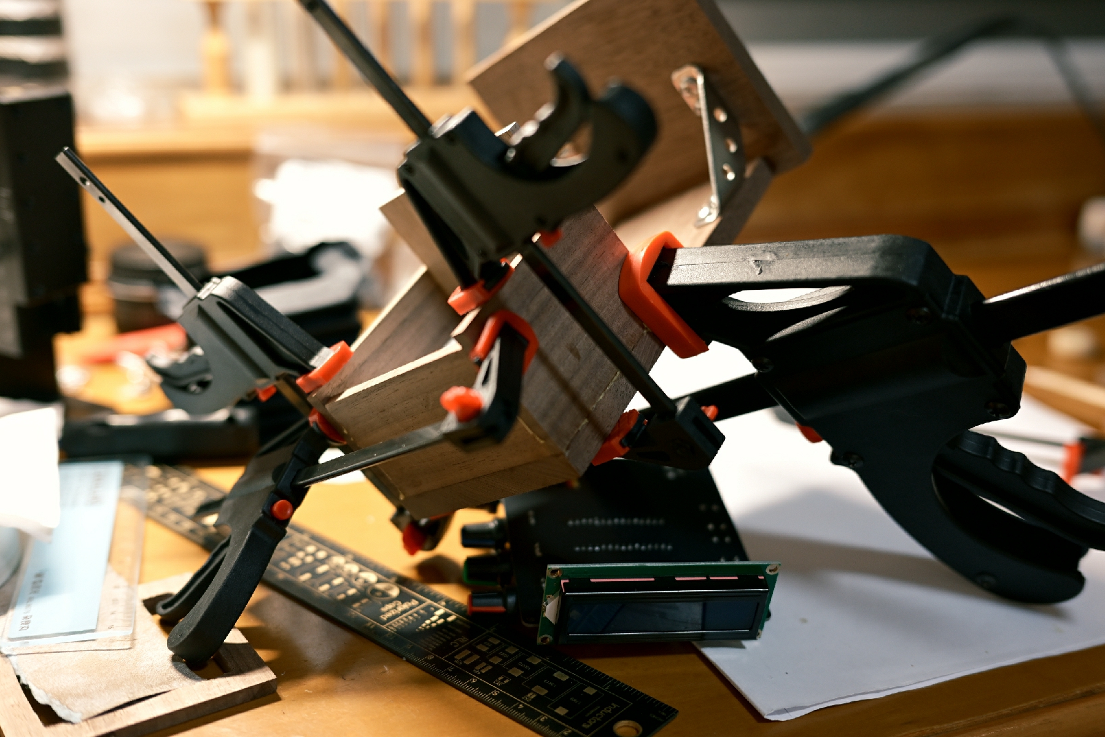
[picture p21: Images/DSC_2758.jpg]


#### 序号 6 的粘接（这里多出的表格中未给出的木头请忽略）：

> 可以看见提前安置片夹以定位。

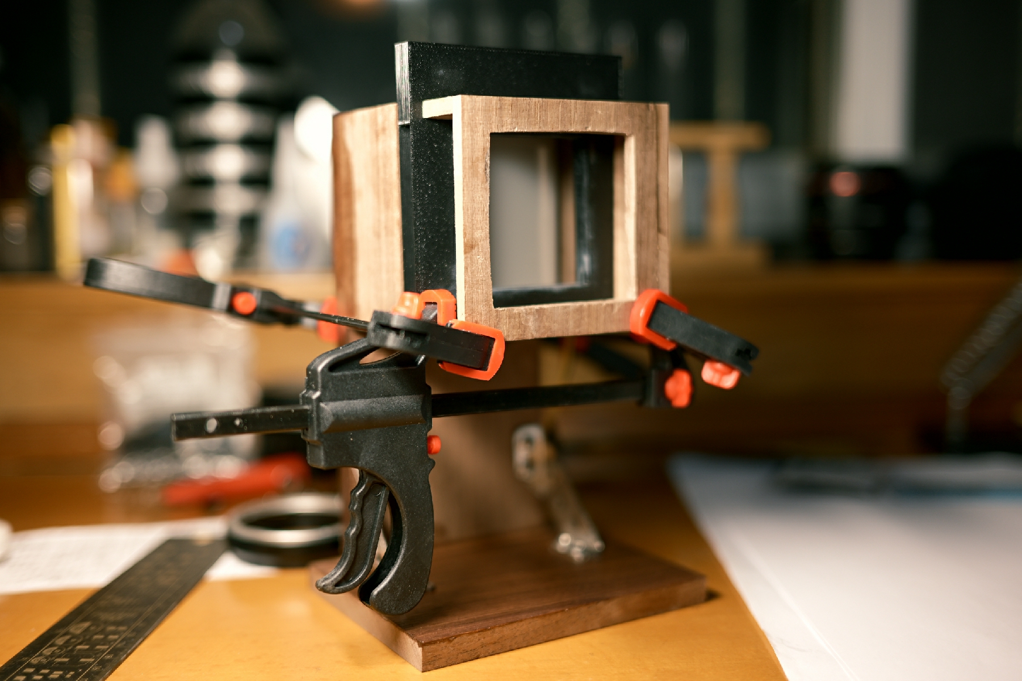
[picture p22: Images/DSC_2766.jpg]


#### 连接滑台：

> 这里可以看见线束如何引出。

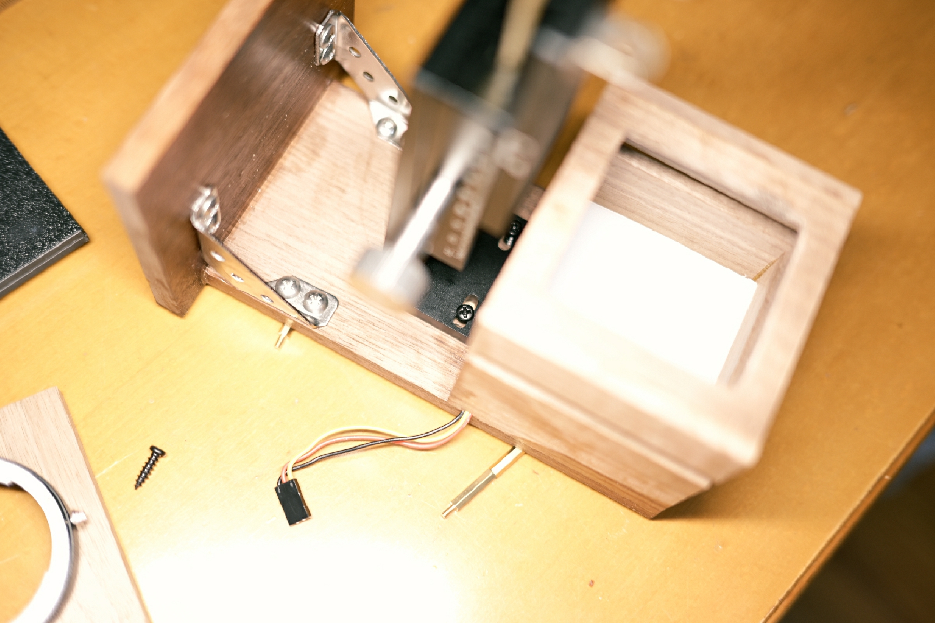
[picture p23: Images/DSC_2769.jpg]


#### 胶水安装片夹的磁铁与玻璃片：

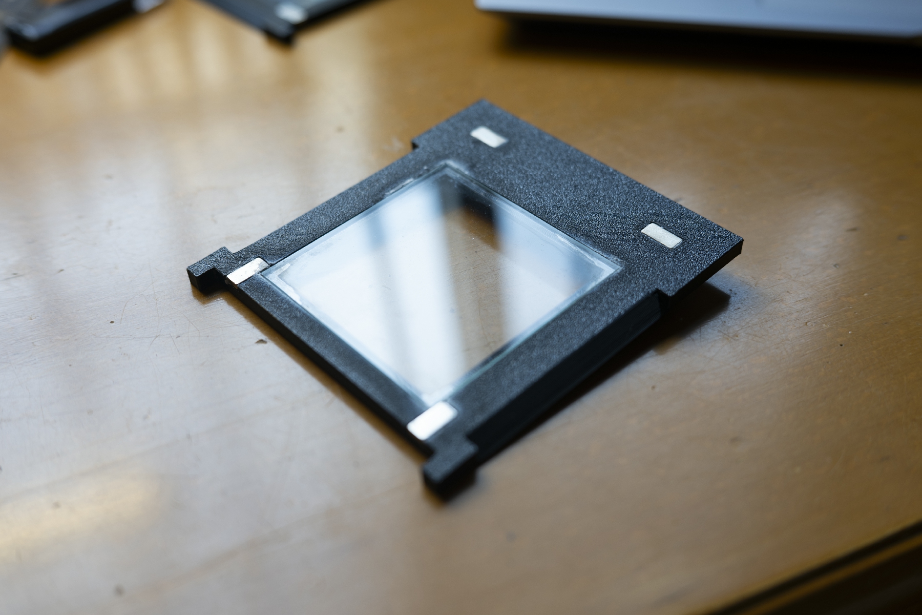
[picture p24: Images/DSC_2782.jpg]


#### 连接整体：

加工

> 给 M6 * 20 * 12 螺丝开孔时靠近板边缘，注意板边缘易损坏。

#### 固定PCB：

> 我使用了四颗 M2*8 螺丝固定。

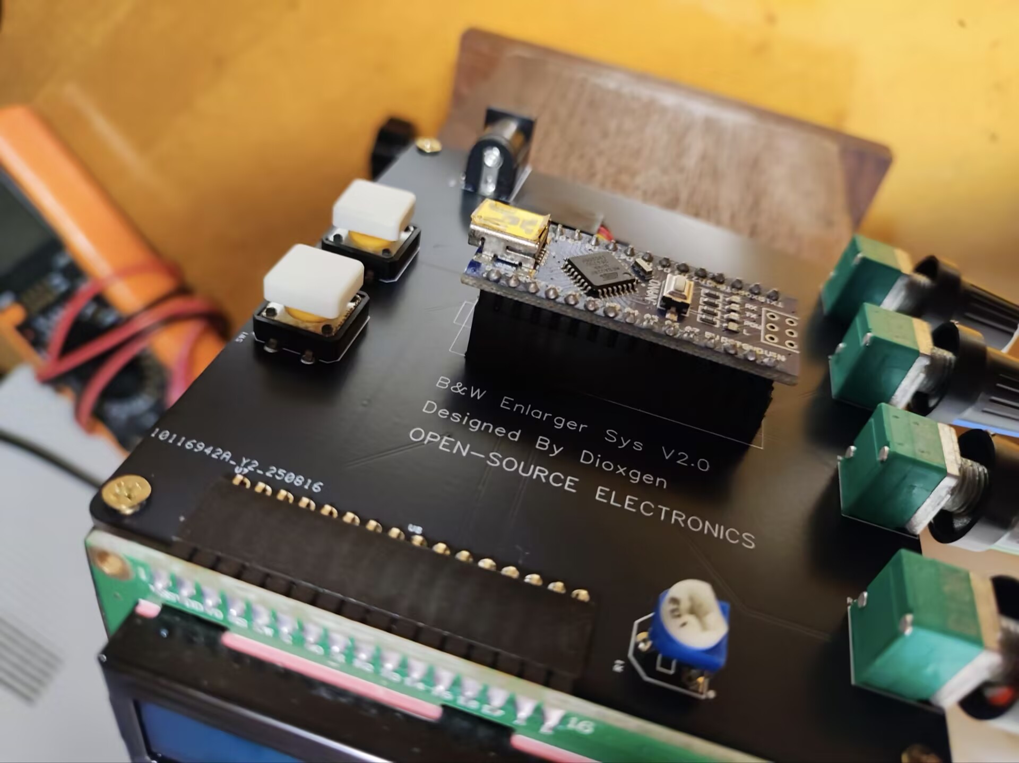
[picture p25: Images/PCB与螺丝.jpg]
PCB与螺丝


<center>四角螺丝固定</center>

#### 完全无误的结构如下图：

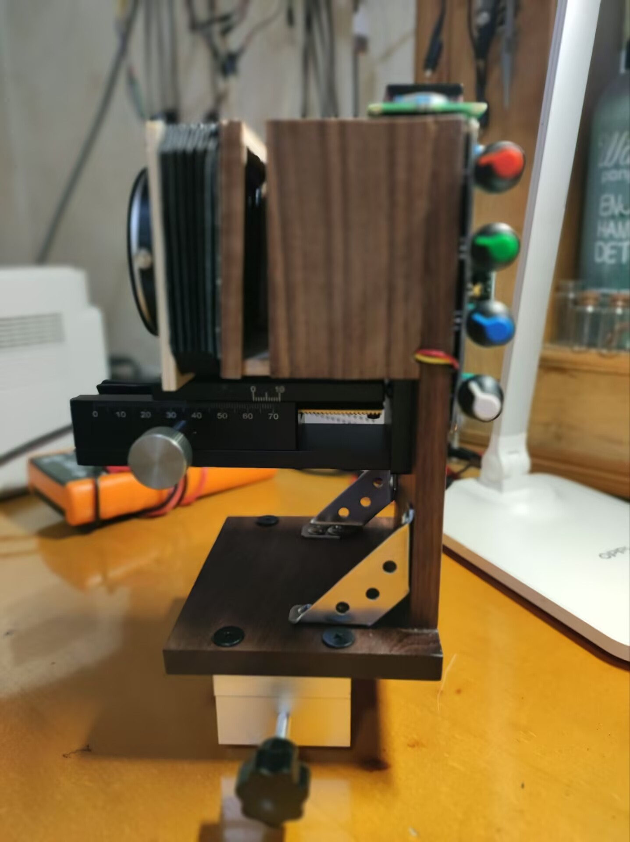
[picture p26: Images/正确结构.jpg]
正确结构


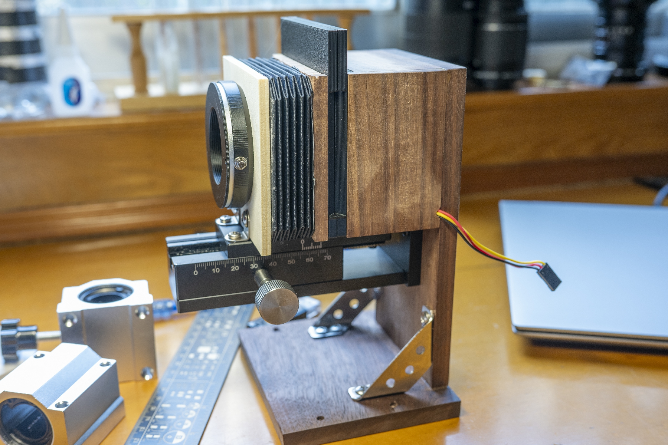
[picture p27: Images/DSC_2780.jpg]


## 成品：

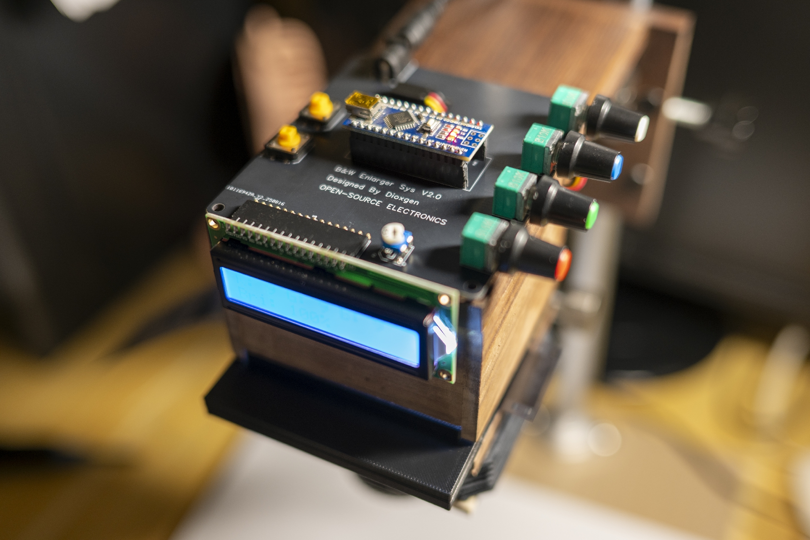
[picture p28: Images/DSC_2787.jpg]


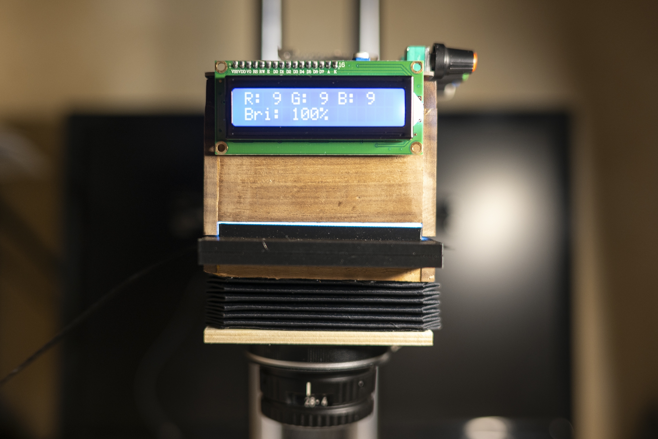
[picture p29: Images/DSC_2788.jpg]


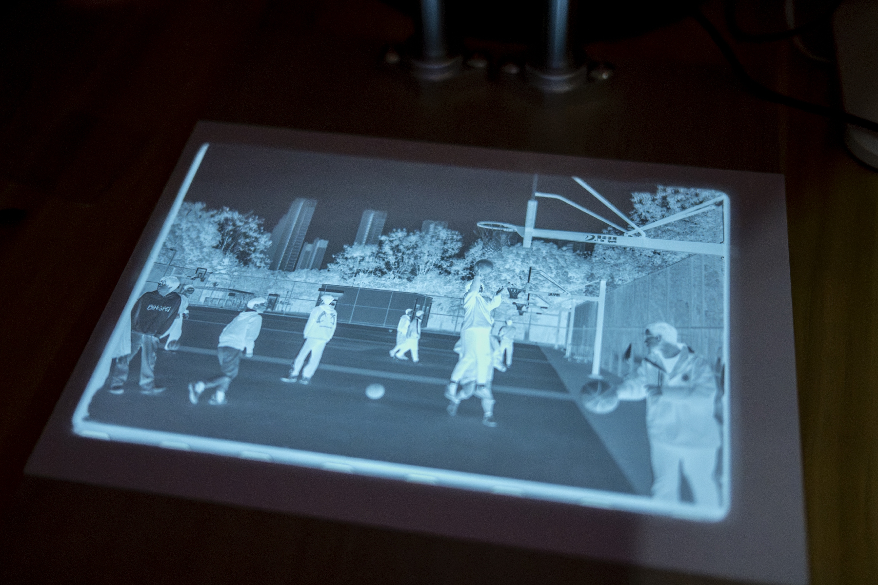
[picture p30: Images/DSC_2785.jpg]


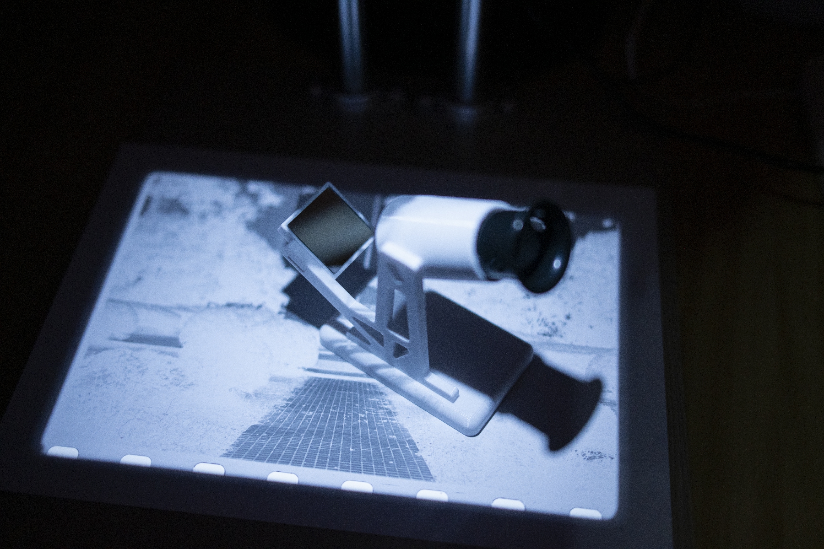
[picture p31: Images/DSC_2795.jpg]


> 颗粒对焦器是我额外设计的，成本仅 7￥，实际使用下来效果不错。

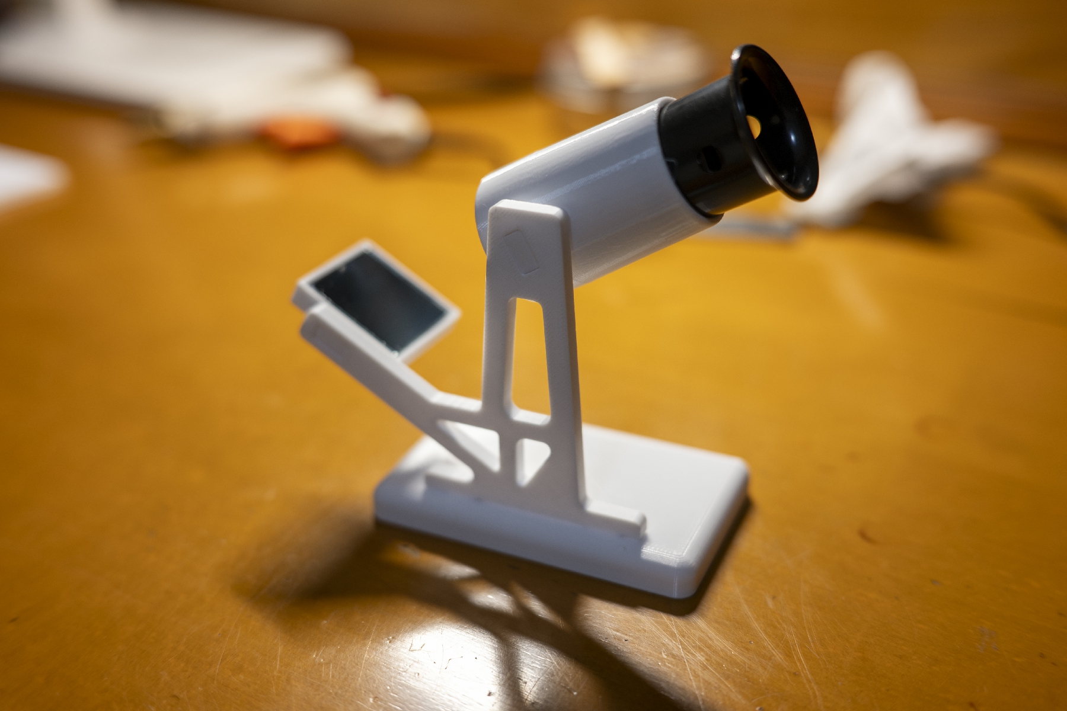
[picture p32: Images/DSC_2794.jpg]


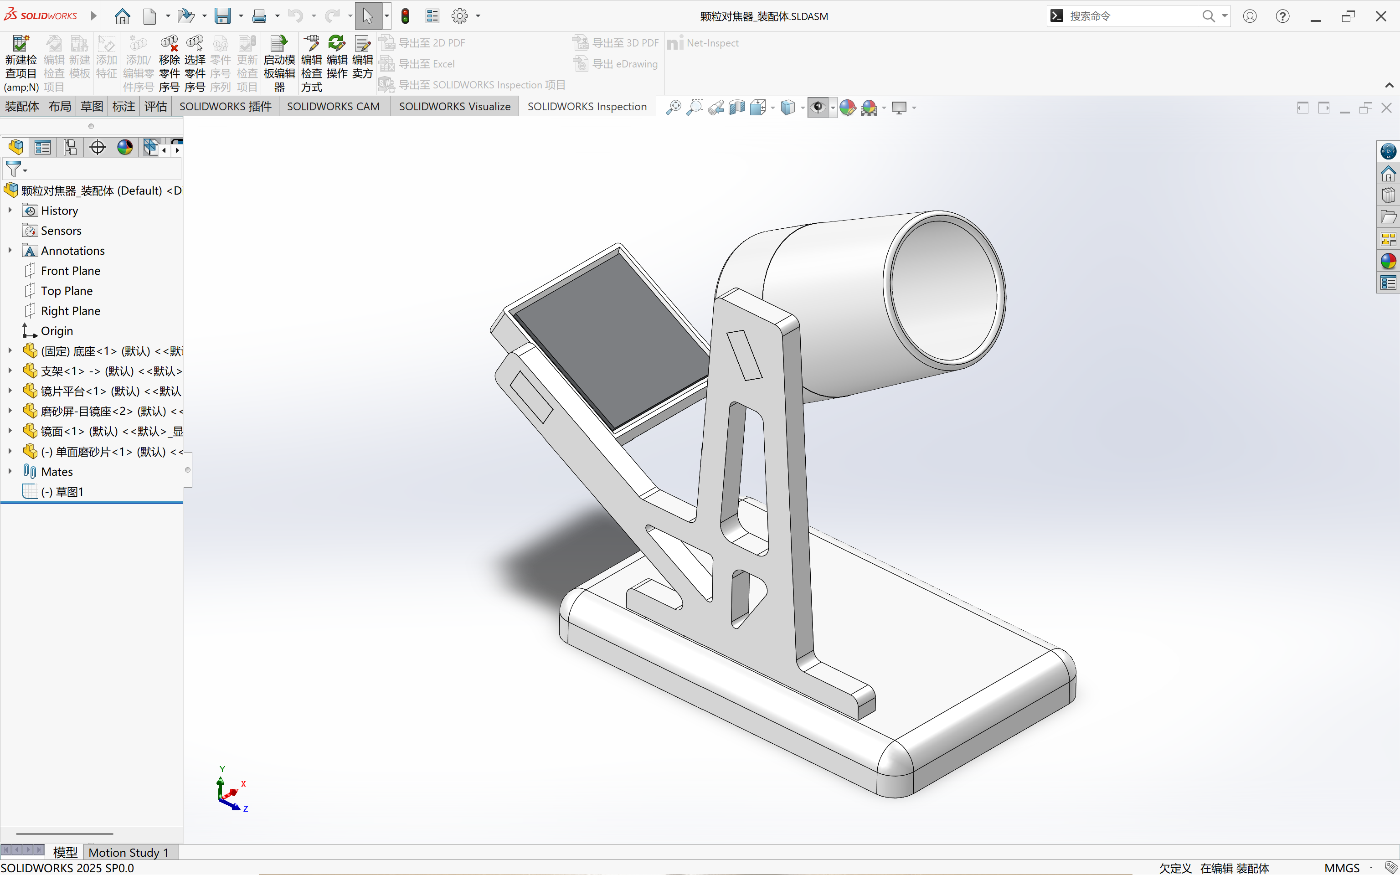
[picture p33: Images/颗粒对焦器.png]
颗粒对焦器


## 测试：

> 相纸：KENTMERE VC SELECT RC 8x10 光面
>
> 显影：D72
>
> 定影：F5
>
> 放大镜头：EL-Nikkor 50mm 1:2.8 N、EL-Nikkor 75mm 1:4 N

##### 关于相纸：

[Kentmere_VC_Select_Technical_Data_Sheet](https://www.freestylephoto.com/static/pdf/product_pdf/kentmere/Kentmere_VC_Select_Technical_Data_Sheet.pdf)

[KENTMERE PHOTOGRAPHIC : VC SELECT TECHNICAL DATA](https://www.digitaltruth.com/products/kentmere_tech/Kentmere_VC_Select.pdf)

##### 关于 D72：

正常的 D72 显影液应是**无色或微黄透明**的。如果它变得像**咖啡色**一样深，说明显影剂已大量氧化，基本失效了。原液的保存在阴凉背光处最长的可以 6 个月。

##### 关于 EL-Nikkor 50mm 1:2.8 N：

6 片 4 组对称高斯结构，最佳倍率在8倍，最大倍率为20倍，光学质量优异。

##### 关于 EL-Nikkor 75mm 1:4 N：

4 片 3 组天塞型结构，镀膜工艺一般，是 N 系列镜头中最轻、最小的一支。

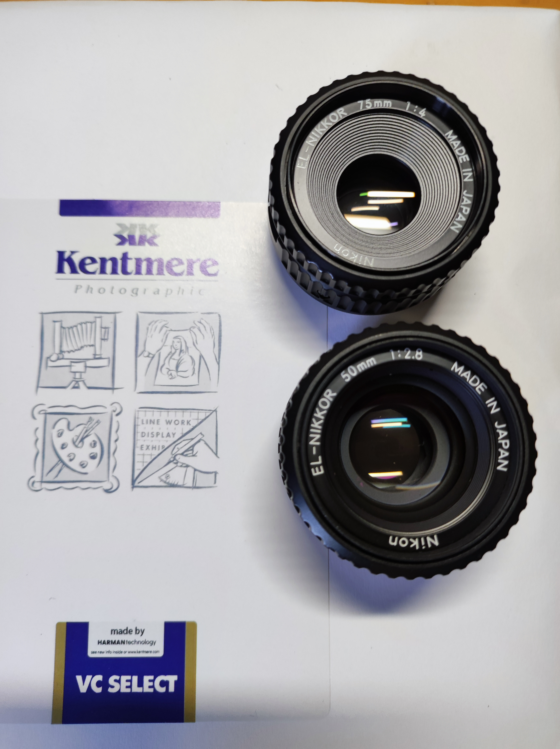
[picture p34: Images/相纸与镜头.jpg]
相纸与镜头


<center>相纸与镜头</center>

------

### 样张 1：

#### 底片信息：

型号：乐凯 1023

相机：Yashikaflex-C

#### 放大信息：

R：0

G：9

B：5

L：77%

T：8s

镜头：EL-Nikkor 75mm 1:4 N（f/16）

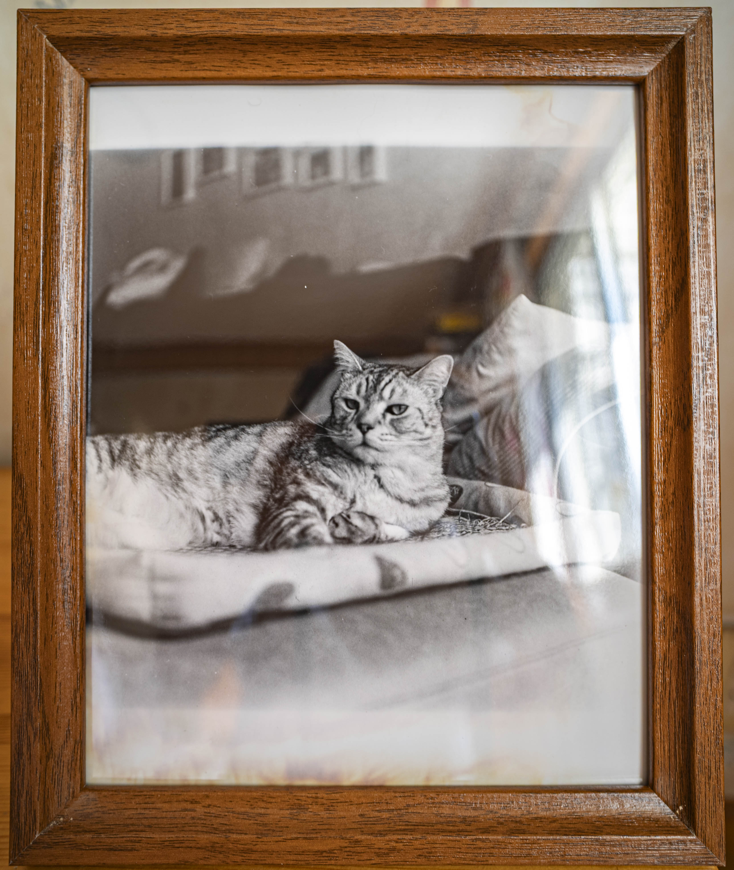
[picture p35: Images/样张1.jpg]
样张1


> 曝光过度了。

------

### 样张 2：

#### 底片信息：

型号：Foma 100 D76

相机：柯尼卡 Auto S2

#### 放大信息：

R：0

G：9

B：3

L：100%

T：2s

镜头：EL-Nikkor 50mm 1:2.8 N（f/8）

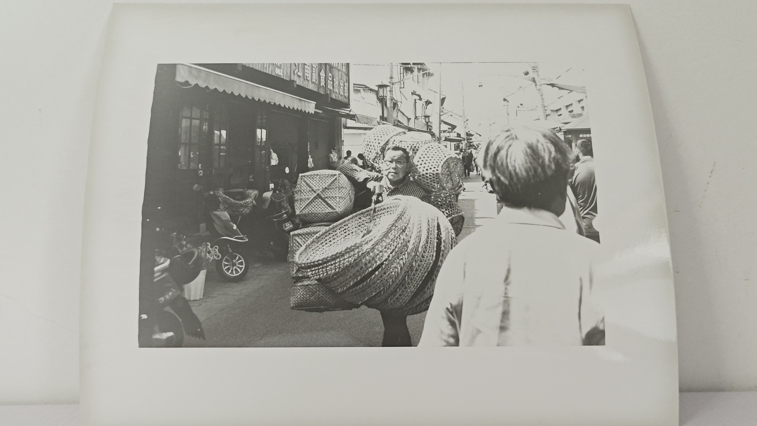
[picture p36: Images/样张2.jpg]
样张2


## 后记：

感谢由 [T_Cz](https://space.bilibili.com/675675040) 提供的暗房。

### 我们用百年前的技艺重现了70年前的老兵风貌：

https://www.bilibili.com/video/BV1Tne7zaEaf

<iframe src="//player.bilibili.com/player.html?isOutside=true&aid=115082272972520&bvid=BV1Tne7zaEaf&cid=31908433349&p=1" width="100%" height="580" scrolling="no" border="0" frameborder="no" framespacing="0" allowfullscreen="true"></iframe>

## Special Thanks:

[KENTMERE PHOTOGRAPHIC : VC SELECT TECHNICAL DATA](https://www.digitaltruth.com/products/kentmere_tech/Kentmere_VC_Select.pdf)

[Kentmere_VC_Select_Technical_Data_Sheet.pdf](https://www.freestylephoto.com/static/pdf/product_pdf/kentmere/Kentmere_VC_Select_Technical_Data_Sheet.pdf)

https://baike.baidu.com/item/%E8%96%84%E6%9D%BF%E7%90%86%E8%AE%BA/2624097

https://zhuanlan.zhihu.com/p/24984524

https://chat.deepseek.com/

[EL-NIKKOR放大镜头 – Dog my cats](https://kusowhu.net/el-nikkor_lens/)

[（转帖）放大头结构和选择方法](http://www.360doc.com/content/17/0606/09/16918133_660392702.shtml)

[配好的d-72的显影液和定影液能放多久\？ - 黑白摄影 - 新摄影论坛](https://forums.nphoto.net/thread/2003-07/20/ff80808108007a730108007aaaa647ef.shtml)

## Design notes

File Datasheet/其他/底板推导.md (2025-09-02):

# 以下是关于底板的选择依据：

> 关于底板**材质**的选择，主要从板材的强度，久置是否易变形等方面考虑：
>
> 1. 若选择黑胡桃木，则该尺寸下日久后变形概率大。
> 2. 若选择胶合木板，则虽然品质欠缺，但是由于胶合木板压制成型，后期不易变形。
>
> 关于底板**厚度**的选择，可以通过一系列公式计算：
>
> 1. 抽象情境：一刚性圆柱插入事先挖有孔洞的无限大各向同性的板中无初始应力或变形，随后圆柱受弯矩使板形变。
> 2. 明确问题：计算板材在受到力偶作用时的最小厚度，以满足最大允许挠度约束。

###### # 注：该底板尺寸较大，与成本紧密挂钩，故对其仔细研究。

##### 关于厚度的分析如下（可跳过）：

当刚性圆柱受弯矩 *M* 作用时，圆柱会产生旋转角度 *θ*。

对于 *Kirchhoff* 板理论，圆柱的转角 *θ* 与弯矩 *M* 的关系为：
$$
\theta = \frac{M}{2\pi D(1-\nu)}
$$
其中，*D* 是板的弯曲刚度，定义为：
$$
D = \frac{Eh^{3}}{12(1-\nu ^{2})}
$$
这里，*E* 是弹性模量，*ν* 是泊松比，*h* 是板厚。

板的最大径向位移发生在圆柱边缘，且与转角 *θ* 和板厚度 *h* 的关系为：
$$
u_{max} = \left | \frac{h}{2} \tan \theta \right |
$$
由于 *θ* 极小（ *≤ 0.5°*），故 *θ ≈ tanθ*：
$$
u_{max} = \left | \frac{h}{2} \theta \right |
$$
联立，忽略符号（仅考虑大小关系），得：
$$
u_{max} = \frac{3M(1+\nu )}{\pi Eh^{2} }
$$

$$
h = \sqrt{\frac{3M(1+\nu )}{\pi Eu_{max} } } 
$$

可见板厚度与圆柱半径无关。

放大机主体不在钢轴的正上方，而是偏移约 *150mm*，所以它会产生一个力矩，这个力矩会使钢轴试图倾斜，从而在底板上产生反力。力矩臂是水平距离，因为力是垂直的重力，所以倾覆力矩是由水平距离引起。

通过经设计得到的板材数据和其他部件的重量，可以估算放大机主体的质量。取胡桃木密度为 **0.65 g/cm³**，得到木制部分约 **394g**，加上滑槽的质量、电气部件、其他部件以及放大镜头，估计主体质量约为 **1kg**。

则倾覆力矩 *M*：
$$
M = F\cdot L = 9.8N \cdot 0.15m=1.47N\cdot m
$$
设最大径向位移为 *0.1mm*，对应约 *0.5°*。

1. 若板材为胡桃木，则取弹性模量 *E = 11GPa*，泊松比 *ν = 0.35*，得：

$$
h=4.15mm
$$

2. 若板材为一般胶合板，则取 *E = 3GPa*，*ν = 0.2*，得：

$$
h=7.50mm
$$

> 查询价格得 30×37.5×2cm 的胡桃木高达 150￥，减去 1cm 厚度仍达 80￥。同 2cm 厚度胶合板则低至 30￥。
>
> 综合成本与实际装配难度保守估计，选择 30×37.5×2cm 的胶合板。

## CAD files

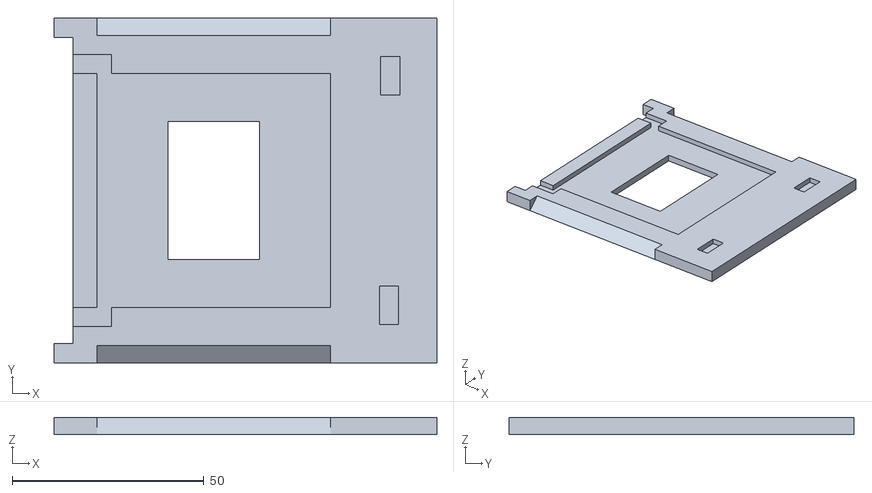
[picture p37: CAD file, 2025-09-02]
Mechanical/3D打印/frame-1-135.stl
100.0 x 90.0 x 4.50

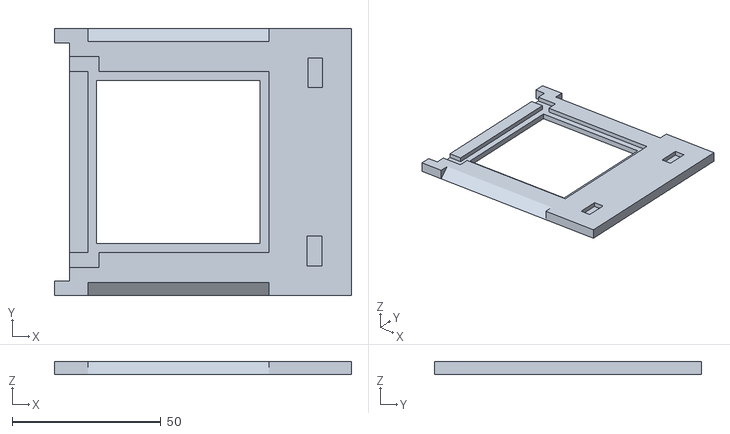
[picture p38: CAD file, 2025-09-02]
Mechanical/3D打印/frame-1-120.stl
100.0 x 90.0 x 4.50

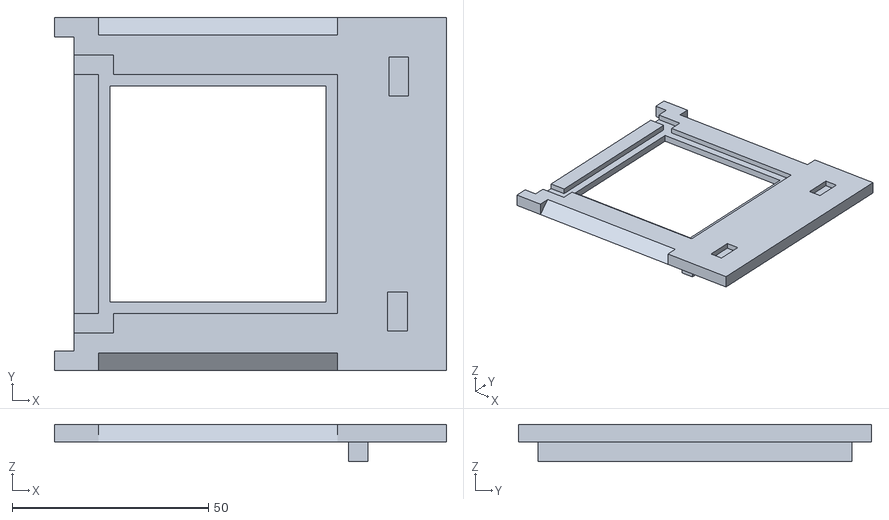
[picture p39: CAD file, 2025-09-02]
Mechanical/3D打印/frame-2.stl
100.0 x 90.0 x 9.50

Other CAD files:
Mechanical/3D打印/frame-1-120.dwg
Mechanical/3D打印/frame-1-135.dwg
Mechanical/3D打印/frame-2.dwg

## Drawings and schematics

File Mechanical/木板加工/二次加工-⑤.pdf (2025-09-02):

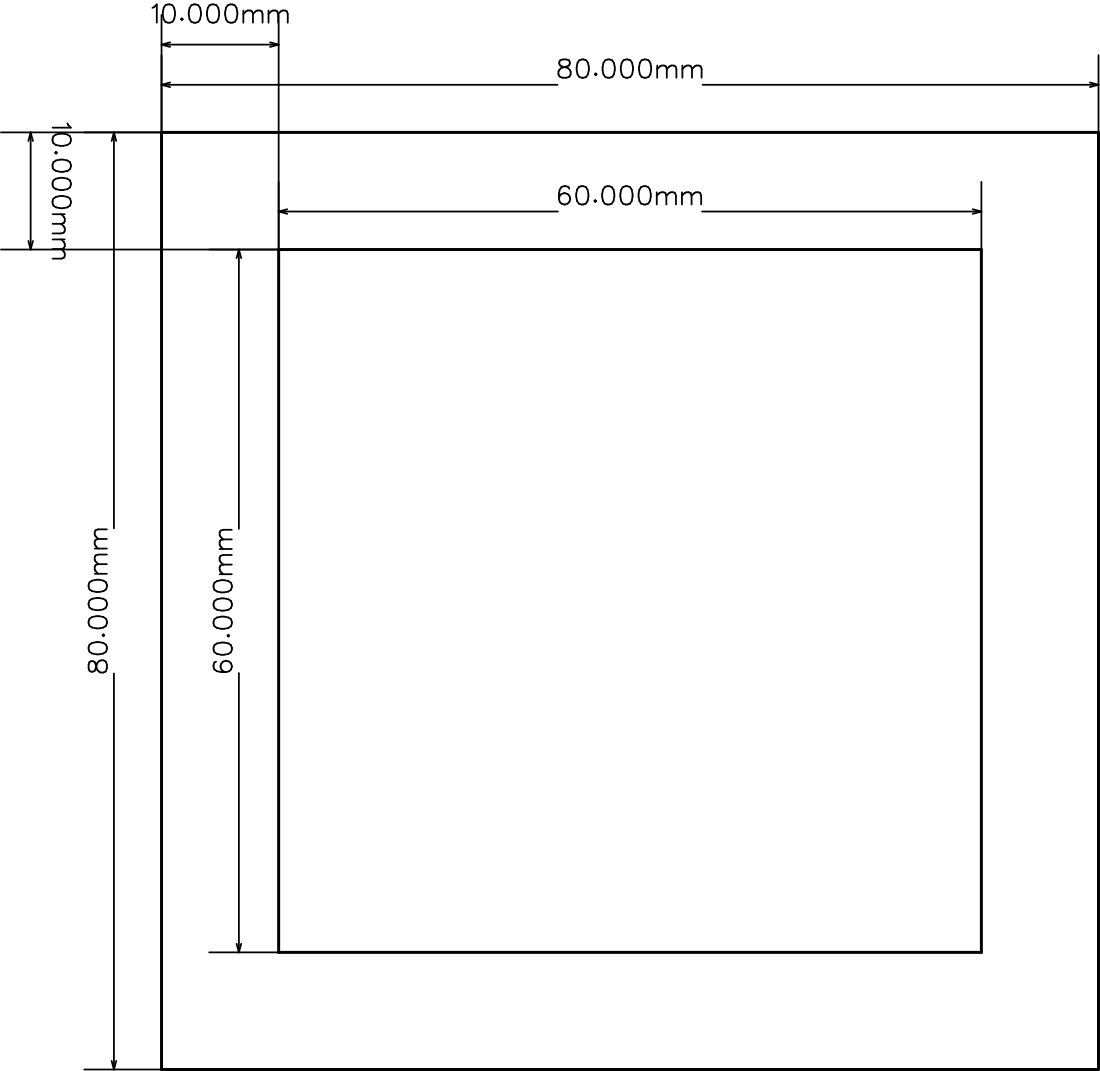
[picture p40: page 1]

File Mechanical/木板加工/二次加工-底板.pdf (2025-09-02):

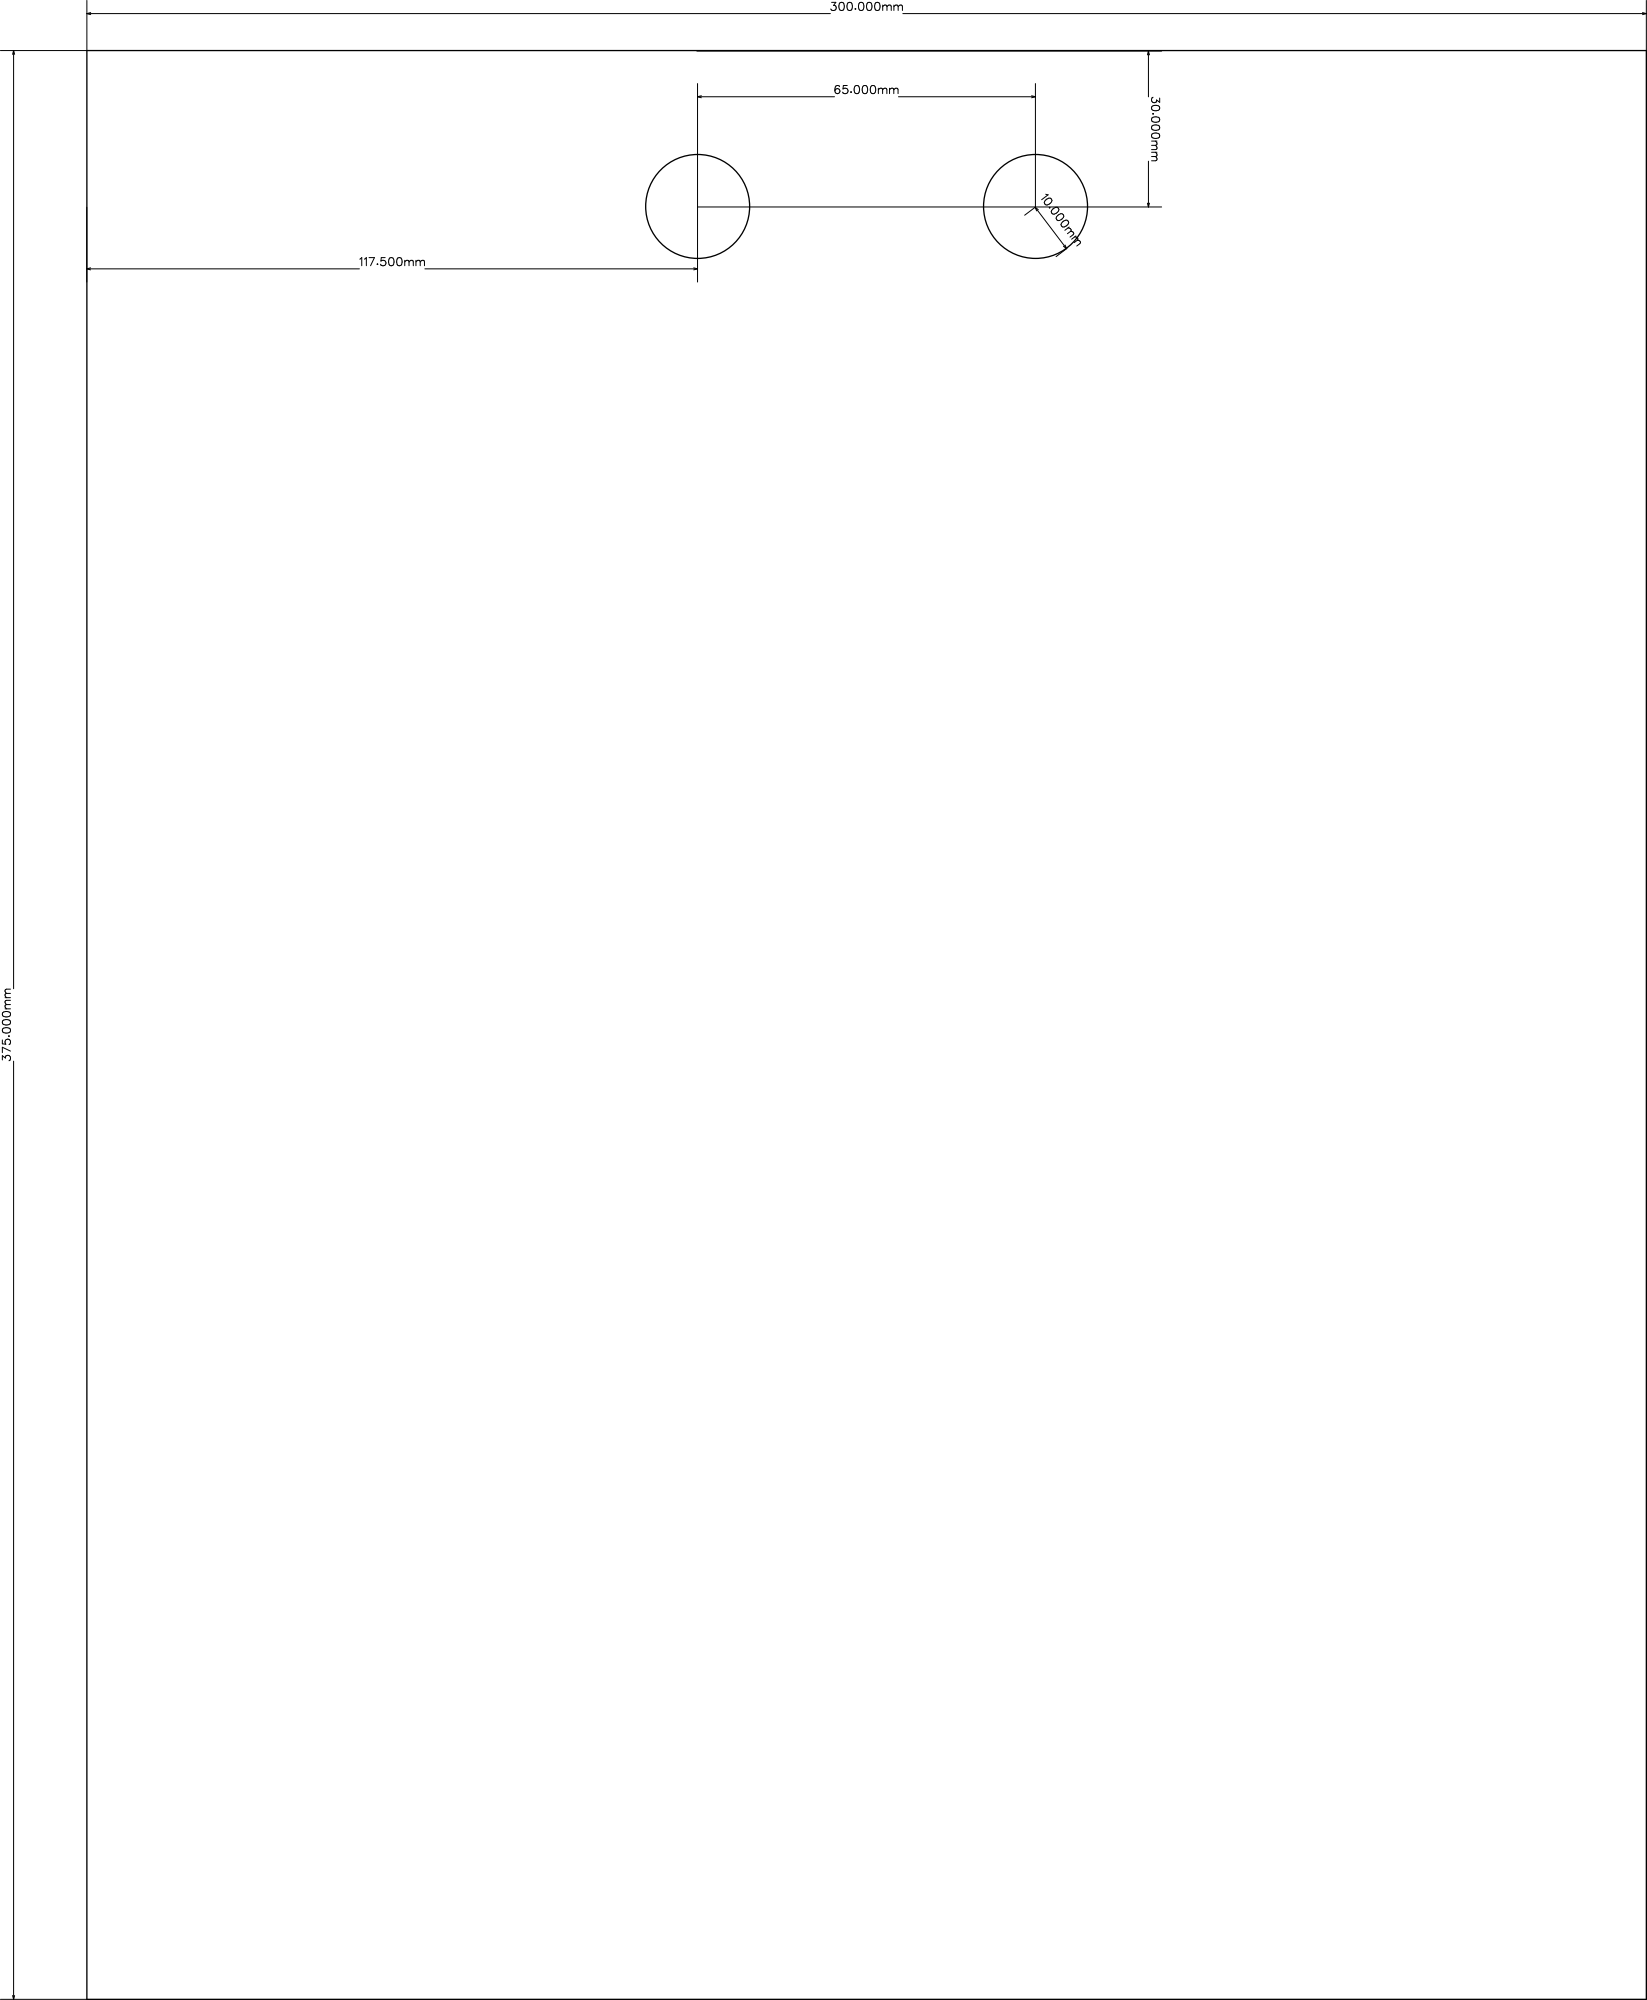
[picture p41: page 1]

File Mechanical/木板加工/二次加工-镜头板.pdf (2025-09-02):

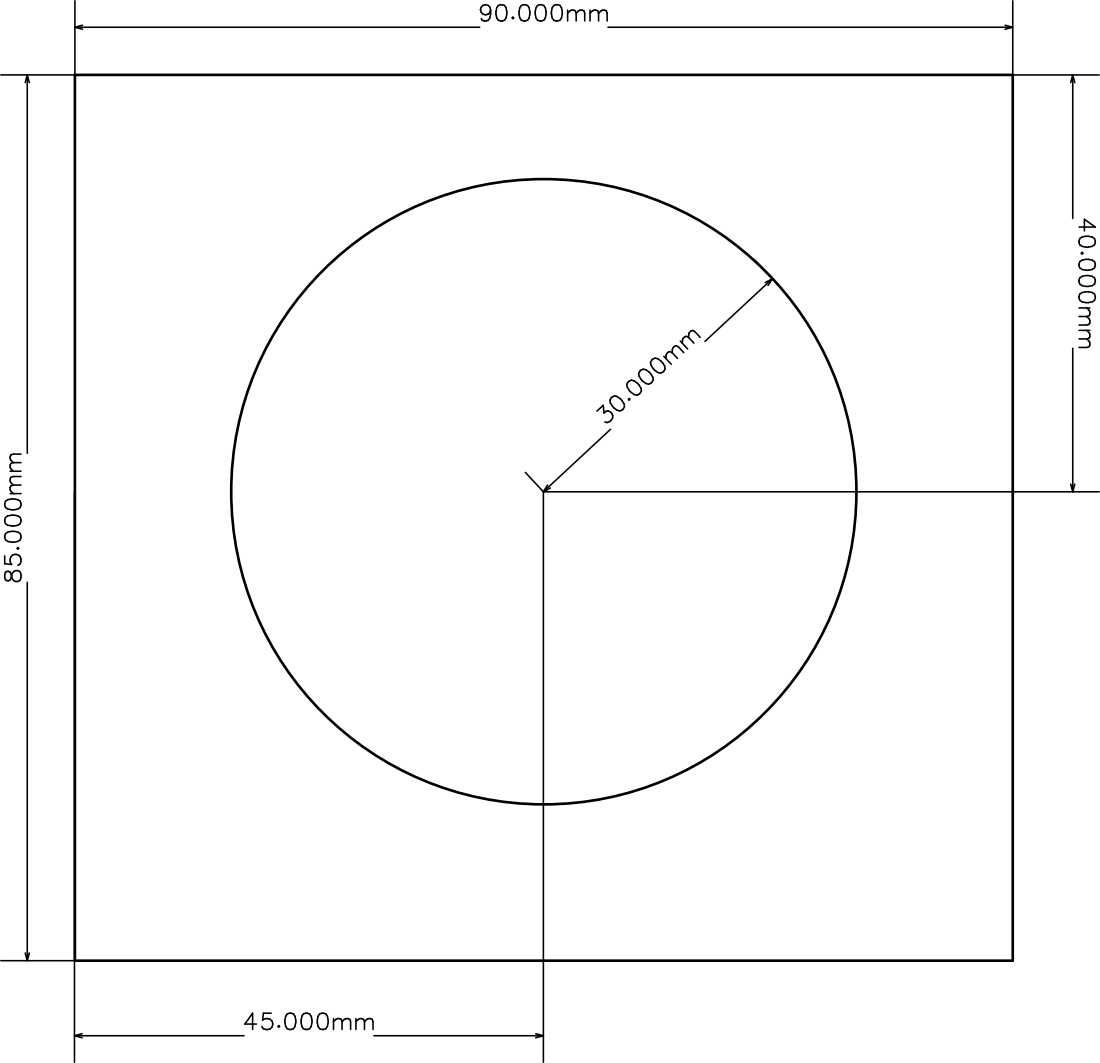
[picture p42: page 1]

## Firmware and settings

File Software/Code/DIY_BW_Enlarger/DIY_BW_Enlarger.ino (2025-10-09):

#include <Adafruit_NeoPixel.h>
#include <LiquidCrystal.h>

// LCD引脚配置
/* LCD RS pin to digital pin 12
 * LCD Enable pin to digital pin 11
 * LCD D4 pin to digital pin 5
 * LCD D5 pin to digital pin 4
 * LCD D6 pin to digital pin 3
 * LCD D7 pin to digital pin 2
 * LCD R/W pin to ground
 * LCD VSS pin to ground
 * LCD VDD pin to 5V
 * LCD A pin to D9
 * LCD K pin to ground
 */
LiquidCrystal lcd(12, 11, 5, 4, 3, 2);
#define LCD_BKL 9

// LED灯带配置
#define LED_PIN 6     // The pin on the Arduino connected to the NeoPixels
#define LED_COUNT 64  // Popular NeoPixel size
Adafruit_NeoPixel pixels(LED_COUNT, LED_PIN, NEO_GRB + NEO_KHZ800);

// 电位器引脚定义
#define R_POT_PIN A0
#define G_POT_PIN A1
#define B_POT_PIN A2
#define BRI_POT_PIN A3

#define MODE_SELECT_PIN 7
#define START_PIN 8         // 在功能1中承担选择与开始曝光功能
#define EXPOSURE_ADJUST 0   // 调整曝光时间状态
#define EXPOSURE_WAITING 1  // 等待开始曝光状态

int ExposureState = EXPOSURE_ADJUST;
int Mode = 0;  // 0为调光模式，1为设置曝光模式
int ExpTime_level = 0;
int ExpTime = 1;  // 曝光时间

unsigned long pressStartTime = 0;                // 按键按下开始时间
bool isPressing = false;                         // 按键是否正在被按下
const unsigned long LONG_PRESS_THRESHOLD = 500;  // 长按阈值(ms)

// 等级数量和校准参数
const int LEVELS = 10;           // 0-9共10个等级
const int DEADZONE_LOW = 30;     // 低端死区阈值
const int DEADZONE_HIGH = 1000;  // 高端死区阈值

// 颜色查找表 (10级)
const uint8_t colorLevels[LEVELS] = { 0, 28, 56, 85, 113, 141, 170, 198, 226, 255 };
float ExpTimeLevels[40] = {1000, 2000, 3000, 4000, 5000, 6000, 7000, 8000, 9000, 10000, 11000, 12000, 13000, 14000, 15000, 16000, 17000, 18000, 19000, 20000, 21000, 22000, 23000, 24000, 25000, 26000, 27000, 28000, 29000, 30000, 31000, 32000, 33000, 34000, 35000, 36000, 37000, 38000, 39000, 40000};  // 曝光时间，单位ms

uint8_t R_val;  // 保存在全局
uint8_t G_val;
uint8_t B_val;
uint8_t brightness;

unsigned long PRESSED_TIME = millis();  // 区分按键短按长按

void setup() {
  pinMode(MODE_SELECT_PIN, INPUT_PULLUP);
  pinMode(START_PIN, INPUT_PULLUP);
  pinMode(LCD_BKL, OUTPUT);

  // 初始化LED灯带
  pixels.begin();
  pixels.clear();
  pixels.setBrightness(0);  // 初始亮度为0
  pixels.show();

  // 初始化LCD
  digitalWrite(LCD_BKL, HIGH);
  lcd.begin(16, 2);
  lcd.print("B/W Enlarger Sys");
  delay(1500);
  lcd.clear();
}

void loop() {
  if (Mode == 0) {
    Dimming();
  } else if (Mode == 1) {
    Exposure();
  }
}

void Dimming() {
  // 读取并校准电位器值
  int rRaw = calibratedRead(R_POT_PIN);
  int gRaw = calibratedRead(G_POT_PIN);
  int bRaw = calibratedRead(B_POT_PIN);
  int briRaw = calibratedRead(BRI_POT_PIN);
  // 映射到0-9等级
  int R_level = map(rRaw, DEADZONE_LOW, DEADZONE_HIGH, 0, LEVELS - 1);
  int G_level = map(gRaw, DEADZONE_LOW, DEADZONE_HIGH, 0, LEVELS - 1);
  int B_level = map(bRaw, DEADZONE_LOW, DEADZONE_HIGH, 0, LEVELS - 1);
  int Bri_level = map(briRaw, DEADZONE_LOW, DEADZONE_HIGH, 0, LEVELS - 1);
  /*
    int R_level = map(rRaw, DEADZONE_HIGH, DEADZONE_LOW, 0, LEVELS - 1);  // 电位器反向适配
    int G_level = map(gRaw, DEADZONE_HIGH, DEADZONE_LOW, 0, LEVELS - 1);
    int B_level = map(bRaw, DEADZONE_HIGH, DEADZONE_LOW, 0, LEVELS - 1);
    int Bri_level = map(briRaw, DEADZONE_HIGH, DEADZONE_LOW, 0, LEVELS - 1);
    */
  // 获取实际颜色值
  R_val = colorLevels[R_level];
  G_val = colorLevels[G_level];
  B_val = colorLevels[B_level];
  brightness = colorLevels[Bri_level];
  // 计算亮度百分比
  int percent = map(Bri_level, 0, LEVELS - 1, 0, 100);

  if (G_level == 0 && B_level == 0) {  //安全灯
    digitalWrite(LCD_BKL, LOW);
  } else {
    digitalWrite(LCD_BKL, HIGH);
  }

  lcd.clear();
  lcd.setCursor(4, 0);
  lcd.print("Dimming");
  delay(1000);
  lcd.clear();

  while (1) {
    rRaw = calibratedRead(R_POT_PIN);
    gRaw = calibratedRead(G_POT_PIN);
    bRaw = calibratedRead(B_POT_PIN);
    briRaw = calibratedRead(BRI_POT_PIN);
    R_level = map(rRaw, DEADZONE_LOW, DEADZONE_HIGH, 0, LEVELS - 1);
    G_level = map(gRaw, DEADZONE_LOW, DEADZONE_HIGH, 0, LEVELS - 1);
    B_level = map(bRaw, DEADZONE_LOW, DEADZONE_HIGH, 0, LEVELS - 1);
    Bri_level = map(briRaw, DEADZONE_LOW, DEADZONE_HIGH, 0, LEVELS - 1);
    /*
    R_level = map(rRaw, DEADZONE_HIGH, DEADZONE_LOW, 0, LEVELS - 1);  // 电位器反向适配
    G_level = map(gRaw, DEADZONE_HIGH, DEADZONE_LOW, 0, LEVELS - 1);
    B_level = map(bRaw, DEADZONE_HIGH, DEADZONE_LOW, 0, LEVELS - 1);
    Bri_level = map(briRaw, DEADZONE_HIGH, DEADZONE_LOW, 0, LEVELS - 1);
    */
    R_val = colorLevels[R_level];
    G_val = colorLevels[G_level];
    B_val = colorLevels[B_level];
    brightness = colorLevels[Bri_level];
    percent = map(Bri_level, 0, LEVELS - 1, 0, 100);

    // 设置LED - 只有在亮度>0时才设置颜色
    pixels.setBrightness(brightness);
    if (brightness > 0) {
      for (int i = 0; i < LED_COUNT; i++) {
        pixels.setPixelColor(i, pixels.Color(R_val, G_val, B_val));
      }
    } else {
      pixels.clear();  // 亮度为0时清除所有LED
    }
    pixels.show();

    if (G_level == 0 && B_level == 0) {  //安全灯
      digitalWrite(LCD_BKL, LOW);
    } else {
      digitalWrite(LCD_BKL, HIGH);
    }

    // 更新LCD显示
    updateLCD(R_level, G_level, B_level, percent);

    delay(10);
    if (digitalRead(MODE_SELECT_PIN) == LOW) {
      delay(50);  // 消抖
      if (digitalRead(MODE_SELECT_PIN) == LOW) {
        Mode = 1;
        delay(300);  // 防止快速切换
        lcd.clear();
        break;
      }
    }
  }
}

void Exposure() {
  lcd.clear();
  lcd.setCursor(4, 0);
  lcd.print("Exposure");
  digitalWrite(LCD_BKL, HIGH);
  delay(1000);
  lcd.clear();

  ExposureState = EXPOSURE_ADJUST;  // 重置状态
  updateExposureLCD();

  while (Mode == 1) {
    // 处理开始按键
    int startPinState = digitalRead(START_PIN);

    // 按键按下
    if (startPinState == LOW && !isPressing) {
      isPressing = true;
      pressStartTime = millis();
    }
    // 按键释放
    else if (startPinState == HIGH && isPressing) {
      isPressing = false;
      unsigned long pressDuration = millis() - pressStartTime;
      // 短按处理
      if (pressDuration < LONG_PRESS_THRESHOLD) {
        if (ExposureState == EXPOSURE_ADJUST) {
          // 调整曝光时间等级
          ExpTime_level++;
          if (ExpTime_level >= 40) {
            ExpTime_level = 0;
          }
          updateExposureLCD();
        } else if (ExposureState == EXPOSURE_WAITING) {
          // 从等待状态返回调整状态
          ExposureState = EXPOSURE_ADJUST;
          updateExposureLCD();
        }
      }
    }
    // 长按处理(按键仍在按下且超过阈值)
    else if (startPinState == LOW && isPressing && millis() - pressStartTime >= LONG_PRESS_THRESHOLD) {
      isPressing = false;  // 防止重复触发
      ExposureState = EXPOSURE_WAITING;
      pixels.clear();  // 关闭光源防止误曝光
      pixels.show();

      lcd.clear();
      lcd.setCursor(0, 0);
      lcd.print("Waiting to START");

      pixels.setBrightness(225);
      for (int i = 0; i < LED_COUNT; i++) {
        pixels.setPixelColor(i, pixels.Color(255, 0, 0));
      }
      pixels.show();

      delay(3000);
      digitalWrite(LCD_BKL, LOW);  // 关闭LCD背光防止漏光
      while (1) {
        startPinState = digitalRead(START_PIN);
        if (startPinState == LOW) {
          delay(2500);  //等待机震消除
          pixels.clear();
          pixels.show();
          pixels.setBrightness(0);
          delay(2500);
          // 开始曝光
          lcd.clear();
          lcd.print("Exposing...");
          START_ENLARGE(ExpTimeLevels[ExpTime_level], R_val, G_val, B_val, brightness);
          ExposureState = EXPOSURE_ADJUST;
          updateExposureLCD();
          break;
        }
      }
    }

    // 处理模式切换按键
    if (digitalRead(MODE_SELECT_PIN) == LOW) {
      delay(50);  // 消抖
      if (digitalRead(MODE_SELECT_PIN) == LOW) {
        Mode = 0;
        delay(300);  // 防止快速切换
        lcd.clear();
        break;
      }
    }
    delay(10);
  }
}

// 校准读取函数 - 解决电位器极限值问题
int calibratedRead(int pin) {
  int raw = analogRead(pin);

  // 应用死区处理
  if (raw < DEADZONE_LOW) return 0;
  if (raw > DEADZONE_HIGH) return 1023;

  // 映射到有效范围
  return map(raw, DEADZONE_LOW, DEADZONE_HIGH, 0, 1023);
}

// 调光模式下的LCD显示
void updateLCD(int R_lvl, int G_lvl, int B_lvl, int percent) {
  static unsigned long lastUpdate = 0;
  if (millis() - lastUpdate < 200) return;  // 200ms刷新间隔
  lastUpdate = millis();
  // 第一行显示RGB等级
  lcd.setCursor(0, 0);
  lcd.print("R: ");
  lcd.print(R_lvl);
  lcd.print(" G: ");
  lcd.print(G_lvl);
  lcd.print(" B: ");
  lcd.print(B_lvl);

  // 第二行显示亮度信息和百分比
  lcd.setCursor(0, 1);
  lcd.print("Bri: ");
  lcd.print(percent);
  lcd.print("% ");
}

// 曝光模式下的LCD显示
void updateExposureLCD() {
  lcd.clear();
  lcd.setCursor(0, 0);
  lcd.print("Exposure Time:");
  lcd.setCursor(0, 1);
  lcd.print(ExpTimeLevels[ExpTime_level] / 1000);
  lcd.print("s");
}

// 开始曝光函数
void START_ENLARGE(int EXPOSURE_TIME, int R, int G, int B, int L) {  // L为Luminance
  // 开启LED
  pixels.setBrightness(L);
  for (int i = 0; i < LED_COUNT; i++) {
    pixels.setPixelColor(i, pixels.Color(R, G, B));
  }
  pixels.show();

  // 曝光计时
  delay(EXPOSURE_TIME);

  // 关闭LED
  pixels.clear();
  pixels.show();
  pixels.setBrightness(0);

  // 显示曝光完成信息
  //digitalWrite(LCD_BKL, HIGH);
  lcd.clear();
  lcd.print("Exposure Done");
  delay(3000);
}

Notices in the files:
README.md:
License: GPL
